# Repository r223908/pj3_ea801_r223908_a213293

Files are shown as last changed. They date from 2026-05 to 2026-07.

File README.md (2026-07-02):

### EA801 - PROJETO 3

### Câmbio CVT (v2) com BitDogLab V7

**Autores:** 
- Raul Galdino Tancredo (RA: 223908 / [@r223908](https://github.com/r223908))
- Arthur Lucas Da Silva Nogueira (RA: 213293 / [@arthurnog](https://github.com/arthurnog)))

**Professor:** Eric Rohmer

* **Proposta de projeto**: [Proposta em G-Docs](https://docs.google.com/document/d/12xUf4pp4VCcdJPwbZHKw6q6G0AQpYL8BC8JdEnKDbEA/edit?usp=sharing) (acesso "Comentador" para UNICAMP)
* **Relatório de projeto**: [Relatório em G-Docs](https://docs.google.com/document/d/11B9UFEimS15q4Ivua8mCu4cjH7NtBMuLyvma5xU35qU/edit?usp=sharing) (acesso "Comentador" para UNICAMP)
* **Demonstração do projeto no YouTube**: [Vídeo](https://youtube.com/shorts/MMiuudLj5G8)

---
## ⚙️ DESCRIÇÃO DO SISTEMA (v2)
O sistema desenvolvido consiste na implementação de uma bancada de testes para um **Câmbio de Transmissão Continuamente Variável (CVT)** simulado, controlado remotamente via interface sem fio. O projeto utiliza a plataforma BitDogLab V7 como unidade central de processamento, integrando comunicação serial, controle de potência e telemetria. O controle é dividido em dois eixos de atuação:
1. Eixo motor: Um motor de corrente contínua (DC), simulando a rotação do motor primário, controlado via PWM mas com a rotação travada em 100%.
2. Atuador do câmbio: Um segundo motor acoplado a um sistema de fuso (atuador linear), responsável por alterar a posição física da correia do câmbio CVT.

A interface homem-máquina (IHM) é realizada de forma remota através de um módulo Bluetooth (conectado à interface UART da placa) com a integração de um aplicativo no celular. O display OLED da placa é utilizado para exibir a telemetria em tempo real.

A realimentação da posição do atuador do CVT é realizada por meio de um sensor de distância óptico Time of Flight (ToF) VL6180X. Cabe ressaltar que o atual protótipo apresenta diversas otimizações mecânicas e elétricas em relação ao projeto original desenvolvido na etapa anterior da disciplina (PJ2).

<figure align="center">
    <figcaption><i>Diagrama de blocos do projeto.</i></figcaption>
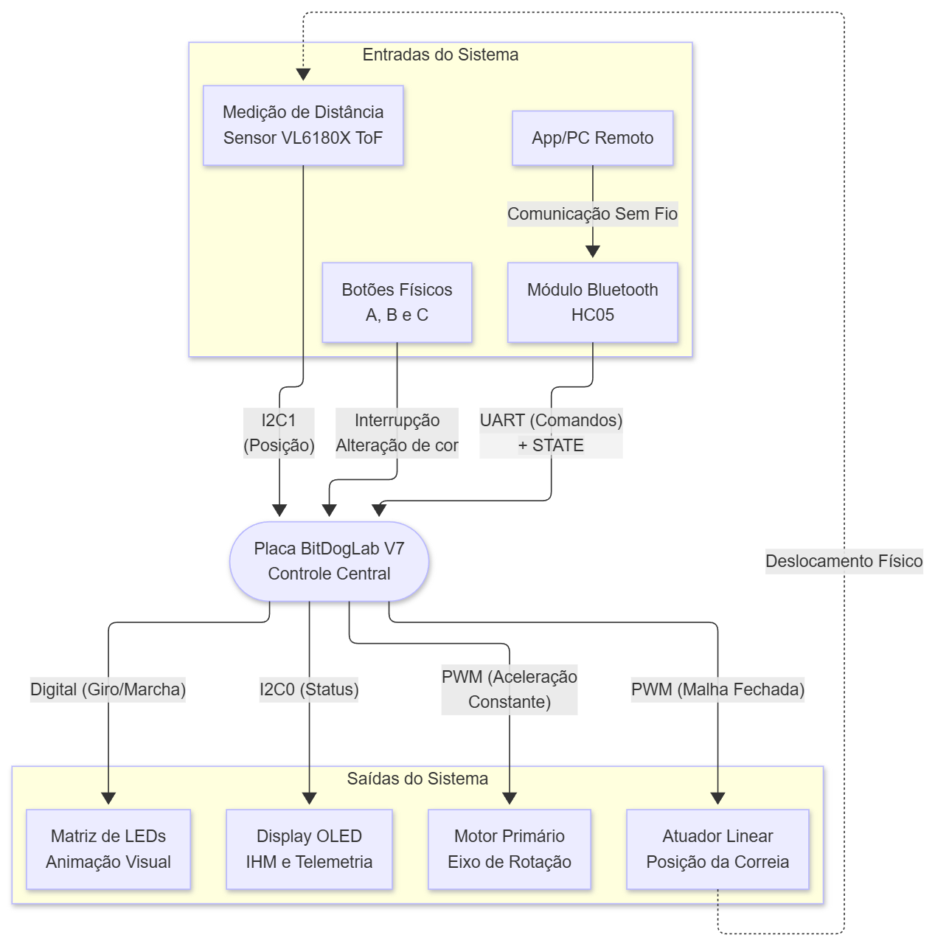
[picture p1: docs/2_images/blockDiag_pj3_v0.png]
    
    </br>
</figure>

<figure align="center">
    <figcaption>
        <i>Projeto em CAD 3D (PJ3).
        <br>PDF 3D (abrir com Foxit ou Adobe): <a href="https://github.com/r223908/pj3_ea801_r223908_a213293/blob/main/docs/6_CAD-files/ea801_pj3_cvt_pdf3D.PDF">/docs/6_CAD-files/ea801_pj3_cvt_pdf3D</a></i></i>
    </figcaption>
    <table align="center">
    <tr>
    <td align="center">
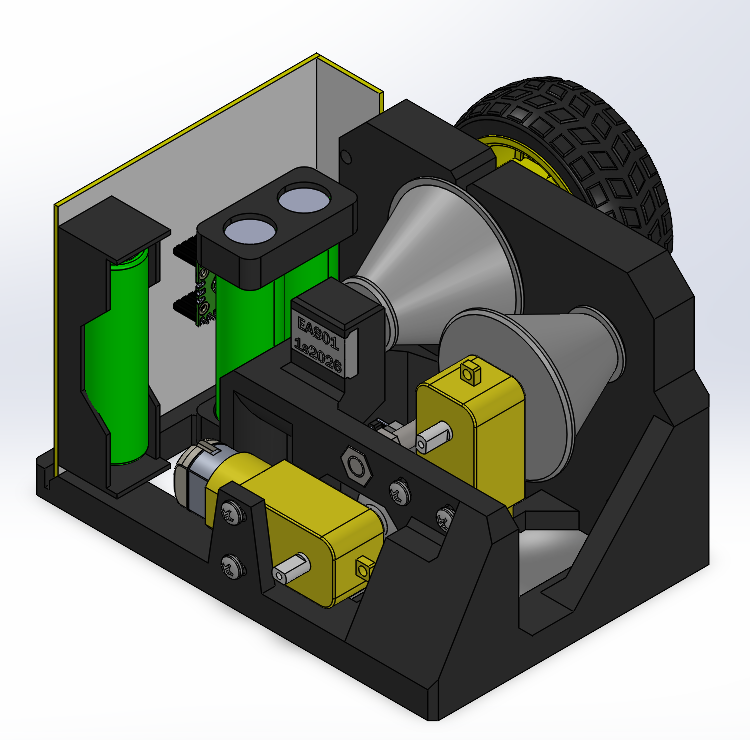
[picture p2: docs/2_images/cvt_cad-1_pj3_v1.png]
        <br>
    </td>
    <td align="center">
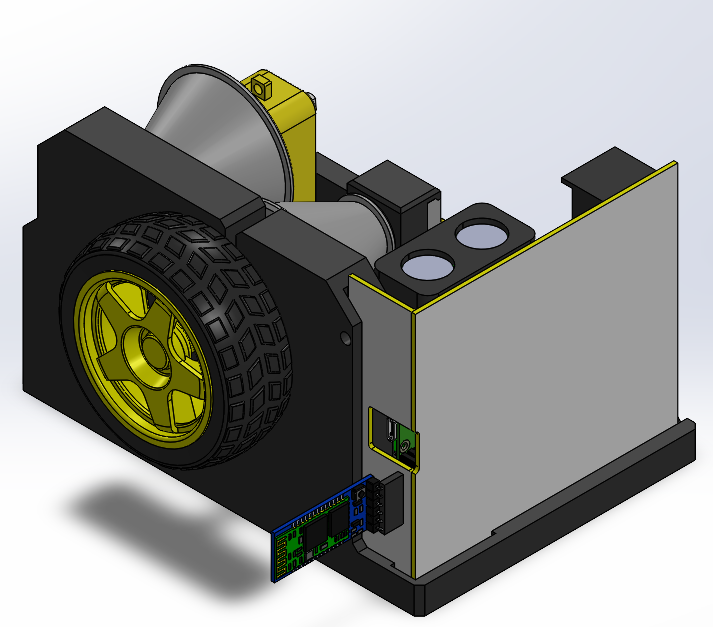
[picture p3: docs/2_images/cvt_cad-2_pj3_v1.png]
        <br>
    </td>
    </tr>
</table>
</figure>

<figure align="center">
    <figcaption>
        <i>Equipamento montado #1 (PJ3).</i>
    </figcaption>
    <table align="center">
    <tr>
    <td align="center">
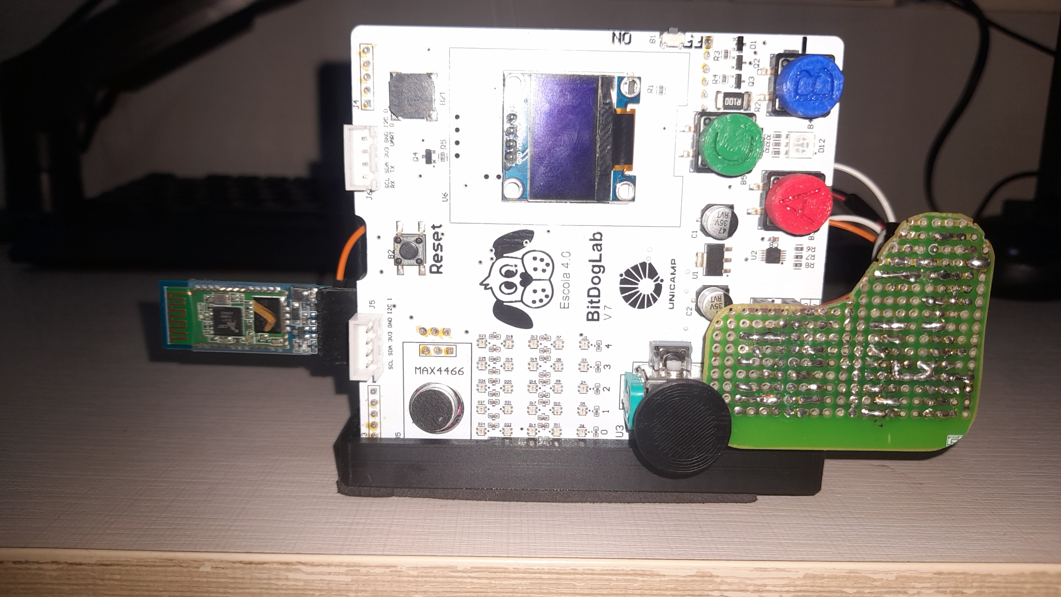
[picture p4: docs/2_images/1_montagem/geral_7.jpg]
        <br>
    </td>
    <td align="center">
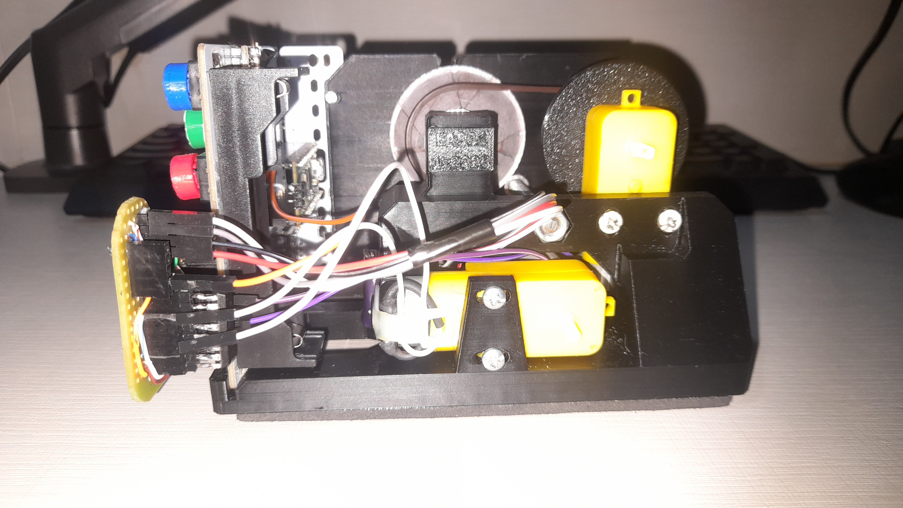
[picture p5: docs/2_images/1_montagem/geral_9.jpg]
        <br>
    </td>
    </tr>
</table>
</figure>

<figure align="center">
    <figcaption>
        <i>Equipamento montado #2 (PJ3).</i>
    </figcaption>
    <table align="center">
    <tr>
    <td align="center">
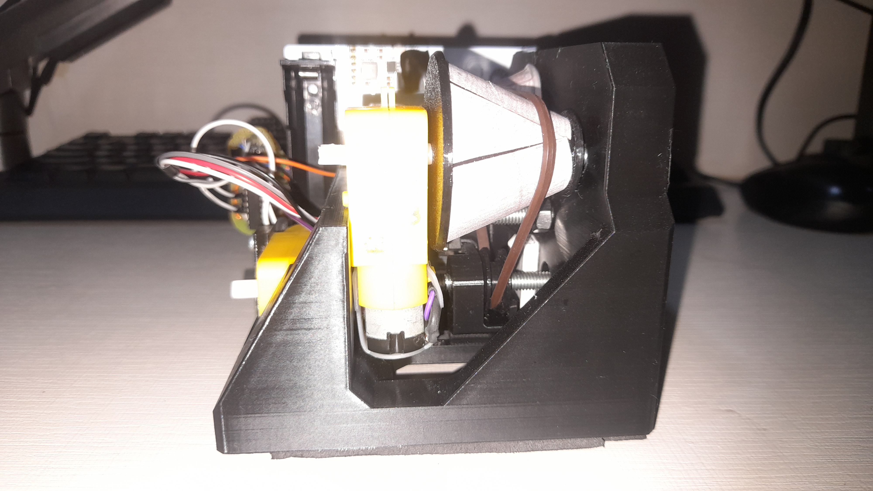
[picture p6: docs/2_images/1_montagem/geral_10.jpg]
        <br>
    </td>
    <td align="center">
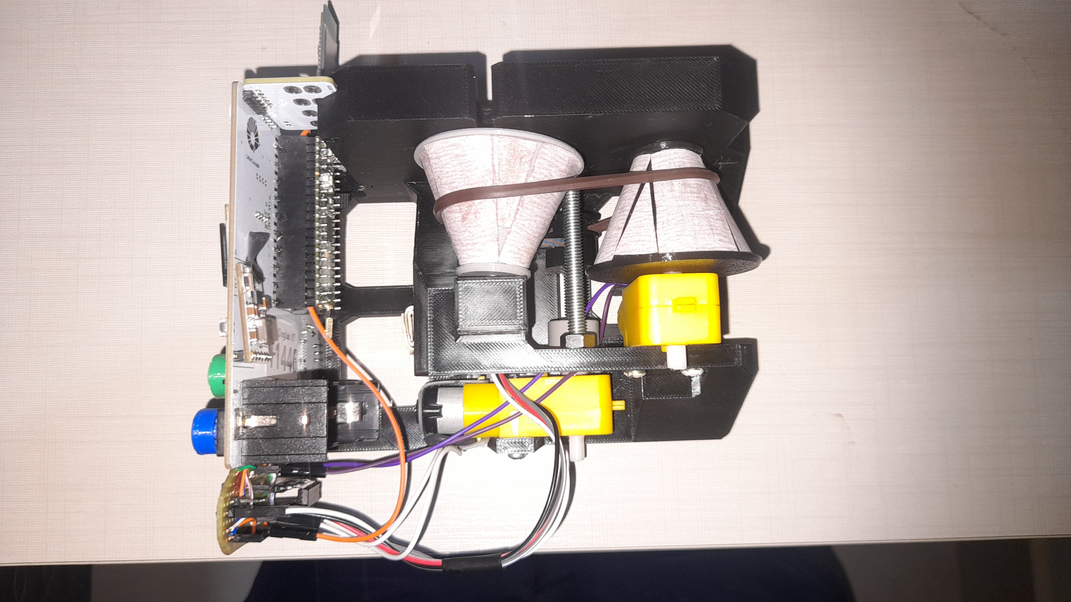
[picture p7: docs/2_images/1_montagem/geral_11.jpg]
        <br>
    </td>
    </tr>
</table>
</figure>

<figure align="center">
    <figcaption><i>Equipamento montado #3 (PJ3).</i></figcaption>
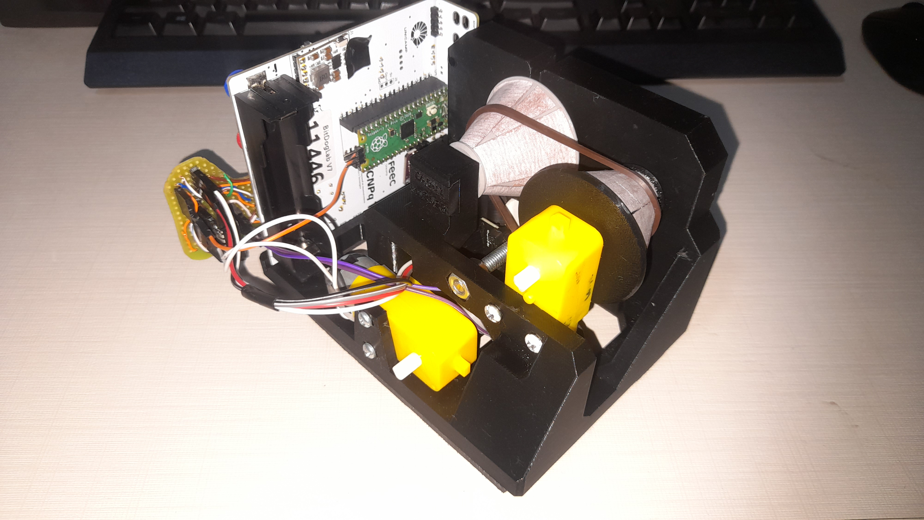
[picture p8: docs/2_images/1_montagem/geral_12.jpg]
    
    </br>
</figure>

---
## ❗REQUISITOS
- 1x BitDogLab V7.
- 2x motores DC com caixa de redução
- 2x capacitores cerâmicos 100 nF (cód.: 104)
- 1x Ponte H L293D (CI) para ambos os motores.
- 1x Sensor ToF VL6180X
- Placa de fenolite para a shield da BitDogLab
- Jumpers M-M e M-F.
- 3x pilhas 18650: 2x para os motores e 1x para a placa
- *Case* com cabos para 2 pilhas 18650 em paralelo.
- Cabo micro USB (usar apenas para passar a programação, com as pilhas desconectadas).
- Módulo Bluetooth HC-05.
- Anel o-ring ou elástico para o câmbio.
- Elementos de fixação
    - 1x Parafuso ISO 4017 M6x15 (Contra-eixo do cone principal)
    - 1x Parafuso ISO 4017 M6x60 (fuso do CVT)
    - 2x Porca ISO 4032 M6 (Espaçador no fuso do CVT e guia da polia)
    - 1x Arruela ISO 7093 Ø6 (Espaçador no fuso do CVT)
    - 4x Parafuso auto atarrachante 9/64"x1" (ou 1/8"x1" - Ø x Comprimento)
- Peças impressas em 3D
- Ambiente de desenvolvimento configurado para MicroPython.

---
## 🔧CONFIGURAÇÕES
- BitDogLab V7: Transferir os arquivos **main.py**, **setup.py**, **vl6180x.py** e **ssd1306.py** para a placa via USB.
- Ligação das pontes H e motores conforme **/docs/images/schematic_pj3.png**
- Módulo Bluetooth HC05 configurado com AT Mode usando **hc05_atMode_config.py**
- Sensor VL6180X calibrado conforme **/libs/tools/vl6180x_calibrate**

---
## 📚 REFERÊNCIAS
1. Repositório BitDogLab V7: [Repositório no GitHub](https://gitlab.unicamp.br/fabiano/bitdoglab-v7)
2. Banco de Informação de Hardware: [BitDogLabV7_BIH](https://docs.google.com/document/d/13-68OqiU7ISE8U2KPRUXT2ISeBl3WPhXjGDFH52eWlU/edit?tab=t.0)
3. LEGO Continuous Variable Transmission (CVT) V3 [Link YouTube](https://www.youtube.com/watch?v=sa60egMprYc)
4. LEGO Simple CVT (Continuously Variable Transmission) [Link YouTube](https://www.youtube.com/watch?v=1y5fQr0dDVg)
5. Time-of-Flight (ToF) proximity sensor and ambient light sensing (ALS) module [VL6180X](https://www.st.com/en/imaging-and-photonics-solutions/vl6180x.html)
6. Using one or more VL6180X 20cm Time-of-Flight proximity sensor with Arduino [Link YouTube](https://www.youtube.com/watch?v=_H9D0czQpSI)

---
## 📄LICENÇA
* Ver o arquivo `LICENSE`.

---
## 📂 ESTRUTURA DO PROJETO
``` text
├── .vscode/                        → Configurações para o ambiente de trabalho no VSCode
├── docs/                           → Documentação do projeto
│   ├── 1_folhas-de-dados/          → Folhas de dados dos equipamentos utilizados
│   ├── 2_images/                   → Imagens para relatórios e referências
│   ├── 3_mermaid-files/            → arquivos para gerar os diagramas de bloco e gantt
│   ├── 4_kicad-pj3/                → Projeto KiCad para a plaquinha shield
│   ├── 5_video/                    → Vídeo do equipamento em operação
│   ├── 6_CAD-files/                → Arquivos .stl e PDF_3D da montagem
│   └── (...)                       → Proposta e relatório
├── libs/
│   ├── tools/                      → Códigos para configuração dos equipamentos                           
│   └── (...)                       → Bibliotecas
├── src/                            
│   └── main.py                     → Código-fonte
├── .micropico                      → Arquivo necessário para a extensão Pi PICO no VSCODE
├── LICENSE                         → Licença de uso do código
└── README.md                       → Resumo e estrutura do projeto
```

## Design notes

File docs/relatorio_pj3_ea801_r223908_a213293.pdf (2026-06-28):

## UNICAMP - Universidade Estadual de Campinas

### FEEC - Faculdade de Engenharia Elétrica e de Computação

Câmbio CVT (v2) com BitDogLab V7 RELATÓRIO DE PROJETO

Link deste documento (acesso Comentador para UNICAMP): Link (https://docs.google.com/document/d/11B9UFEimS15q4Ivua8mCu4cjH7NtBMuLyvma5xU35qU/edit?usp=sharing) Repositório no GitHub (https://github.com/r223908/pj3_ea801_r223908_a213293)
Vídeo de demonstração (https://www.youtube.com/shorts/MMiuudLj5G8)
Arthur Lucas Da Silva Nogueira | RA: 213293
Raul Galdino Tancredo | RA: 223908

Prof. Eric Rohmer

Campinas
2026

### 1. Descrição do Sistema

O sistema desenvolvido consiste na implementação de um Câmbio de Transmissão Continuamente Variável (CVT) simulado e controlado remotamente via interface sem fio. O projeto utiliza a plataforma BitDogLab V7 como unidade central de processamento, integrando comunicação serial, controle de potência e telemetria. Utilizando uma ponte H L293D, o controle dos motores é dividido em dois eixos de atuação:
1. Eixo motor: motor de corrente contínua (DC) responsável pela força motriz principal, conectado ao cone principal.
2. Atuador do câmbio: motor de corrente contínua acoplado a um sistema de fuso (atuador linear), responsável por alterar a posição física da correia do câmbio CVT. No sistema de fuso, há a polia (que tem o anel o-ring/elástico girando livremente) e a guia, que faz com que o movimento de rotação do fuso se transforme em movimento linear.

A interface homem-máquina (IHM) é realizada de forma remota através de um módulo Bluetooth (conectado à interface UART da placa) com a integração de um aplicativo no celular (“Arduino Bluetooth Control” na Play Store do Google). O display OLED da placa é utilizado para exibir a telemetria em tempo real.

Para termos um controle de posicionamento do câmbio, foi incluído o sensor Time of Flight (ToF) VL6180X da STM. Com este sensor acoplado ao câmbio linear, temos um feedback de posicionamento para controlar a velocidade de saída do câmbio.

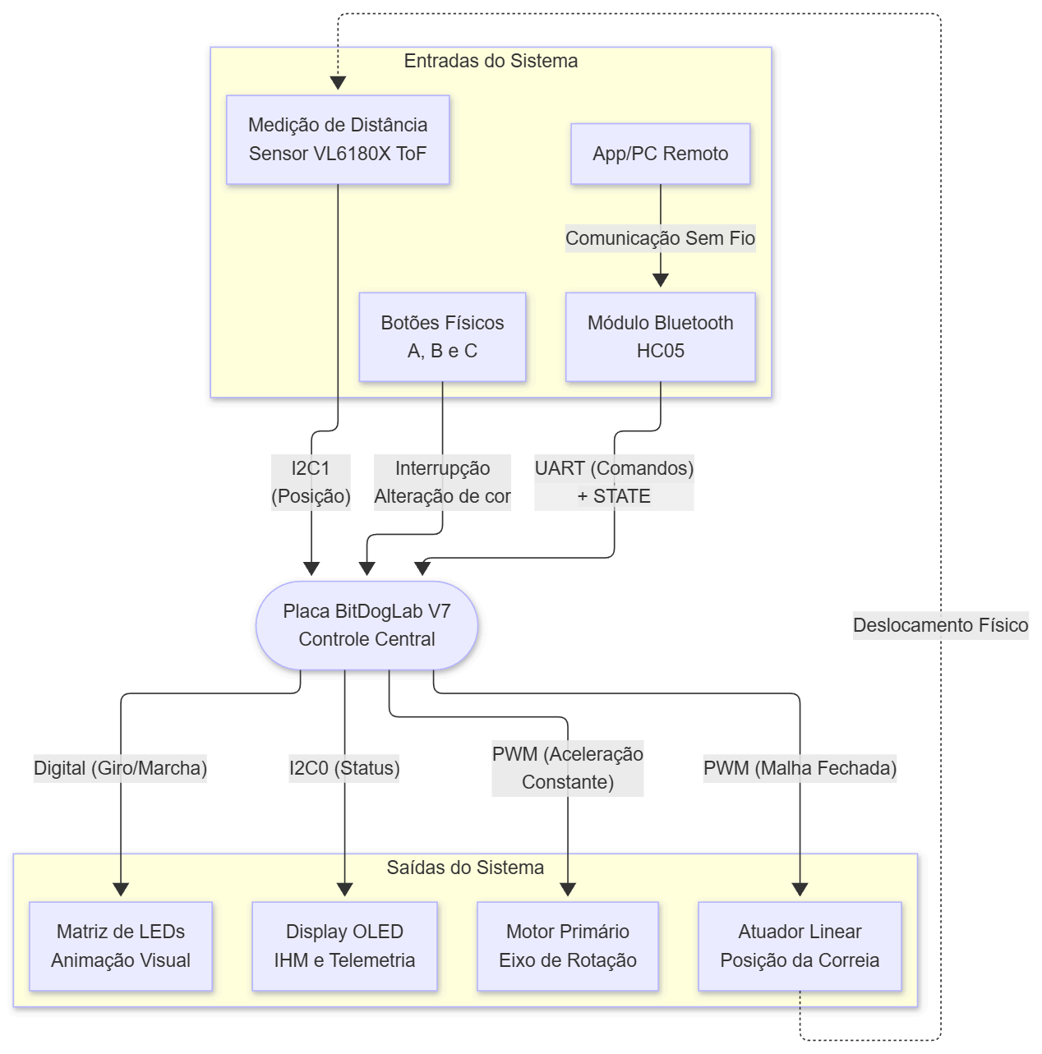
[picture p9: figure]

Figura 1 - Arquitetura do sistema.

### 2. Código fonte

- Códigos de configuração e teste:
- Configuração módulo Bluetooth: libs/tools/hc05_atMode_config.py (https://github.com/r223908/pj3_ea801_r223908_a213293/blob/main/libs/tools/hc05_atMode_config.py)
- Mapeamento de comandos Bluetooth: libs/tools/hc05_bluetooth_mapping.py (https://github.com/r223908/pj3_ea801_r223908_a213293/blob/main/libs/tools/hc05_bluetooth_mapping.py)
- Calibração do VL6180x: libs/tools/vl6180x_calibrate.py (https://github.com/r223908/pj3_ea801_r223908_a213293/blob/main/libs/tools/vl6180x_calibrate.py)
- Teste do VL6180x: libs/tools/vl6180x_test.py (https://github.com/r223908/pj3_ea801_r223908_a213293/blob/main/libs/tools/vl6180x_test.py)

Python

- Biblioteca do sensor VL6180X: libs/vl6180x.py (https://github.com/r223908/pj3_ea801_r223908_a213293/blob/main/libs/vl6180x.py)

"""
GitHub: https://github.com/Ledbelly2142/VL6180X/blob/master/vl6180x.py Author: Ledbelly2142 (https://github.com/Ledbelly2142)
"""

import ustruct
import struct
import time
from machine import I2C, Pin

i2c_tof = I2C(0, sda=Pin(8), scl=Pin(9)) offsetVal = 35

class Sensor:
def __init__(self, i2c, address=0x29): self.i2c_tof = i2c
self._address = address
self.default_settings()
self.init()

def myWrite16(self, register, regValue):
""" write a byte to specified 16 bit register """ return self.i2c_tof.writeto_mem(self._address, register, bytearray([regValue]), addrsize=16), 'big'

def myRead16(self, register):
"""read 1 bit from 16 byte register"""
value = int.from_bytes(
self.i2c_tof.readfrom_mem(self._address, register, 1, addrsize=16), 'big'
)
return value & 0xFFFF

def init(self):
if self.myRead16(0x0016) != 1:
raise RuntimeError("Failure reset")

# Recommended setup from the datasheet self.myWrite16(0x0207, 0x01) self.myWrite16(0x0208, 0x01) self.myWrite16(0x0096, 0x00) self.myWrite16(0x0097, 0xfd) self.myWrite16(0x00e3, 0x00) self.myWrite16(0x00e4, 0x04) self.myWrite16(0x00e5, 0x02) self.myWrite16(0x00e6, 0x01) self.myWrite16(0x00e7, 0x03) self.myWrite16(0x00f5, 0x02) self.myWrite16(0x00d9, 0x05) self.myWrite16(0x00db, 0xce)

self.myWrite16(0x00dc, 0x03) self.myWrite16(0x00dd, 0xf8) self.myWrite16(0x009f, 0x00) self.myWrite16(0x00a3, 0x3c) self.myWrite16(0x00b7, 0x00) self.myWrite16(0x00bb, 0x3c) self.myWrite16(0x00b2, 0x09) self.myWrite16(0x00ca, 0x09) self.myWrite16(0x0198, 0x01) self.myWrite16(0x01b0, 0x17) self.myWrite16(0x01ad, 0x00) self.myWrite16(0x00ff, 0x05) self.myWrite16(0x0100, 0x05) self.myWrite16(0x0199, 0x05) self.myWrite16(0x01a6, 0x1b) self.myWrite16(0x01ac, 0x3e) self.myWrite16(0x01a7, 0x1f) self.myWrite16(0x0030, 0x00)

def default_settings(self): self.myWrite16(0x0011, 0x10) self.myWrite16(0x010A, 0x30) self.myWrite16(0x003f, 0x46) self.myWrite16(0x0031, 0xFF) self.myWrite16(0x0040, 0x63) self.myWrite16(0x002E, 0x01) self.myWrite16(0x0024, 100) self.myWrite16(0x001B, 0x09) self.myWrite16(0x003E, 0x0A) self.myWrite16(0x0014, 0x24) self.myWrite16(0x002D, 0x10) self.myWrite16(0x0022, 0x28) self.myWrite16(0x001C, 0x3F) self.myWrite16(0x0120, 0x01)

def identify(self):
return {
'model': self.myRead16(0x0000),
'revision': (self.myRead16(0x0001), self.myRead16(0x0002)), 'module_revision': (self.myRead16(0x0003), self.myRead16(0x0004)), 'date': self.myRead16(0x006),
'time': self.myRead16(0x008),
}

def address(self, address=None): if address is None:
return self._address
if not 8 <= address <= 127:
raise ValueError("Wrong address") self.myWrite16(0x0212, address) self._address = address

Python

def range(self):
"""Previne falhas elétricas do hardware (I2C OSError) e retorna None de forma segura"""
try:
self.myWrite16(0x0018, 0x01) # Sysrange start

# Timeout simples para evitar travamento em loops infinitos caso o I2C congele

timeout = 50
while (self.myRead16(0x004F) & 0x04) == 0:
time.sleep(0.005)
timeout -= 1
if timeout <= 0:
print("Aviso: Timeout de leitura do sensor ToF.") return None

status = self.myRead16(0x004D) >> 4 distancia_crua = self.myRead16(0x0062) self.myWrite16(0x0015, 0x07) # Clear Interrupt

if status != 0:
print(f"Erro interno do ToF! Código: {status}") return None

distancia_real = distancia_crua
if distancia_real < 0:
distancia_real = 0

return (0 if ((distancia_real - offsetVal) < 0) else (distancia_real -offsetVal))

except OSError:
# Captura o erro EIO [Errno 5] físico sem derrubar o programa principal

print("Alerta: Falha física instantânea de comunicação I2C com o ToF.")
return None
- Setup do projeto: libs/setup.py (https://github.com/r223908/pj3_ea801_r223908_a213293/blob/main/libs/setup.py)

"""
arquivo de importação de bibliotecas, configuração de interfaces e variáveis """

from machine import Pin, ADC, I2C, PWM
import neopixel, utime, machine, time
import ssd1306, vl6180x

# 1. Variáveis Globais e Cores

corVermelha = (20, 0, 0)
corAzul = (0, 0, 20)
corVerde = (0, 20, 0)
cor_travada = corVermelha # Motor começa vermelho ultimo_tempo_btn = 0
ultimo_tempo_pisca = utime.ticks_ms() indice_frame = 0

# 2. Variáveis de Controle do Motor Virtual

CENTRO_JOYSTICK = 32768
ZONA_MORTA = 4000
MAX_LEDS_POR_SEGUNDO = 100 # Ajuste a velocidade máxima aqui

# 3. Configuração dos Botões (A, B e C)

botao_a = Pin(5, Pin.IN, Pin.PULL_UP)
botao_b = Pin(6, Pin.IN, Pin.PULL_UP)
botao_c = Pin(10, Pin.IN, Pin.PULL_UP)

# 4. Configuração do Joystick

joystick_x = ADC(Pin(27))
joystick_y = ADC(Pin(26))
joystick_sw = Pin(22, Pin.IN, Pin.PULL_UP)

# 5. Configuração do Display OLED (SSD1306)

# Usando os pinos I2C0 da BitDogLab V7 (SDA=2, SCL=3) i2c = I2C(1, scl=Pin(3), sda=Pin(2), freq=400000) display = ssd1306.SSD1306_I2C(128, 64, i2c, addr=0x3C) display.fill(0)

display.show()
ATT_DISPLAY_MS = 100

# 6. Configuração da Matriz de LEDs NUM_LEDS = 25

np = neopixel.NeoPixel(Pin(7), NUM_LEDS)
LED_MEIO = 12
# Buffer circular da animação do motor

FRAMES_MOTOR = [[14, 13], [15, 16], [16, 24], [16, 23], [17, 22], [18, 21], [18, 20], [18, 19], [10, 11], [8, 9], [0, 8], [1, 8], [2, 7], [3, 6], [4, 6], [5, 6] ]

# 7. Configuração dos controles de Motor (Ponte H) e PWM da placa

# IMPORTANTE: GPIO 0 e 1 são do Bluetooth. Vamos usar os pinos livres do conector IDC.

# Motor Principal (Eixo) - Assumindo ligação no lado Esquerdo do L293D (Pinos 1, 2 e 7)

Mprincipal_DIR1 = Pin(16, Pin.OUT)
Mprincipal_DIR2 = Pin(17, Pin.OUT)
Mprincipal_PWM = PWM(Pin(18)) | # GP28 vai no pino 1 (EN1,2) do L293D
Mprincipal_PWM.freq(1000)
Mprincipal_PWM.duty_u16(0)
TEMPO_RAMPA_MS = 1000

Python

# Motor Câmbio (Atuador CVT) - EXATAMENTE COMO NO SEU ESQUEMÁTICO (Lado Direito)

Mcambio_DIR1 = Pin(19, Pin.OUT) | # GP18 (Fio Roxo) vai no IN3
Mcambio_DIR2 = Pin(20, Pin.OUT) | # GP20 (Fio Branco) vai no IN4
Mcambio_PWM = PWM(Pin(28)) | # GP19 (Fio Cinza) vai no EN3,4 (Enable/PWM)
Mcambio_PWM.freq(1000)
Mcambio_PWM.duty_u16(0)
TEMPO_PASSO_CVT_MS = 5000 # 2000 ms = 2 segundos

# 8. Configura o LED Azul da placa (GPIO 12) para feedback visual led_azul = machine.Pin(12, machine.Pin.OUT)

led_azul.value(0) # Inicia desligado

# 9. Inicializa a UART0 para o Bluetooth (Pinos do Conector J2)

bluetooth = machine.UART(0, baudrate=9600, tx=machine.Pin(0), rx=machine.Pin(1)) status_bt = machine.Pin(4, machine.Pin.IN) # Pino que vai ler o pino 'STATE' do módulo Bluetooth

# 10. Mapeamento das entradas bluetooth

outButtonDir = '0'
frontDir = 'F'
backDir = 'B'
rightDir = 'R'
leftDir = 'L'
triangleDir = 'T'
circleDir = 'C'
squareDir = 'S'
crossDir = 'X'
startDir = 'A'
pauseDir = 'P'

# 11. Inicializa o sensor

#i2c_tof = I2C(0, sda=Pin(8), scl=Pin(9)) #esta declaracao já está na biblioteca do sensor ToF

i2c_tof = vl6180x.i2c_tof
sensor_tof = vl6180x.Sensor(i2c_tof) # type: ignore
- Arquivo principal: link

from setup import *

# VARIÁVEIS PARA O CVT ASSÍNCRONO BASEADO EM DISTÂNCIA cvt_em_movimento = False

direcao_cvt = 0 | # 1 avança (diminui mm), -1 recua (aumenta mm)
alvo_tof_mm = 0.0 | # Distância que queremos atingir
janela_leituras = [] | # type: list[float]
TAMANHO_JANELA = 30 | # Média das últimas 30 leituras
PASSO_MM = 4.0 | # Quantos mm o câmbio anda por vez
MAX_DIST_MM = 24.0 | # Fundo do câmbio (0%)

MIN_DIST_MM = 1.0 # Batente do câmbio (100%)

# ==========================================

# FUNÇÕES DE HARDWARE (MOTORES, TELA E SENSOR)

# ==========================================

# MÉTODO DE LEITURA E SINCRONIZAÇÃO DO SENSOR TOF

def sincronizar_posicao_cvt():
global posicao_cvt
print("Sincronizando posição atual do sensor ToF...") leituras_locais = []

# Coleta 10 amostras rápidas para ignorar ruídos de leitura única for _ in range(10):

leitura = sensor_tof.range()
if leitura is not None and leitura > 0: leituras_locais.append(leitura)
utime.sleep(0.01)

if len(leituras_locais) > 0:
distancia_calculada = sum(leituras_locais) / len(leituras_locais) else:
# Se falhar totalmente por erro I2C, assume a última posição segura conhecida

distancia_calculada = MAX_DIST_MM

# Trava dentro dos limites físicos do projeto

distancia_calculada = max(MIN_DIST_MM, min(MAX_DIST_MM, distancia_calculada))

# 1. Atualiza a variável global de porcentagem

porcentagem_calculada = ((MAX_DIST_MM - distancia_calculada) / (MAX_DIST_MM -MIN_DIST_MM)) * 100
posicao_cvt = max(0, min(100, int(porcentagem_calculada)))

print(f"Posição Sincronizada: {distancia_calculada:.1f} mm ({posicao_cvt}%)") return distancia_calculada

# Lida com as informações do display OLED

def printOled(velocidade, direcao, posicao_cvt, bt_conectado):
texto_sentido = "Horario" if direcao == 1 else "Anti-Hor." texto_sentido = "Parado" if velocidade == 0 else texto_sentido texto_bt = "ON" if bt_conectado == 1 else "OFF" display.fill(0)
display.text("Cambio CVT", 20, 0)
display.text("-" * 16, 0, 10) display.text(f"Motor: {texto_sentido}", 0, 25) display.text(f"Pos. CVT: {posicao_cvt}%", 0, 40) display.text(f"Bluetooth: {texto_bt}", 0, 55) display.show()

# Controle do motor principal

def controlar_motor_principal(velocidade_percentual, direcao, fazer_rampa=False): if fazer_rampa and velocidade_percentual > 0:
passos = 10
tempo_por_passo = (TEMPO_RAMPA_MS / 2000) / passos passo_pwm = max(1, velocidade_percentual // passos) for v in range(velocidade_percentual, -1, -passo_pwm): Mprincipal_PWM.duty_u16(int((v / 100) * 65535)) utime.sleep(tempo_por_passo) Mprincipal_DIR1.value(0)
Mprincipal_DIR2.value(0)
Mprincipal_PWM.duty_u16(0) utime.sleep(0.05)
if direcao == 1:
Mprincipal_DIR1.value(1)
Mprincipal_DIR2.value(0)
else:
Mprincipal_DIR1.value(0)
Mprincipal_DIR2.value(1)
for v in range(0, velocidade_percentual + 1, passo_pwm): Mprincipal_PWM.duty_u16(int((v / 100) * 65535)) utime.sleep(tempo_por_passo) Mprincipal_PWM.duty_u16(int((velocidade_percentual / 100) * 65535)) else:
if velocidade_percentual > 0:
if direcao == 1:
Mprincipal_DIR1.value(1)
Mprincipal_DIR2.value(0)
else:
Mprincipal_DIR1.value(0)
Mprincipal_DIR2.value(1)
else:
Mprincipal_DIR1.value(0)
Mprincipal_DIR2.value(0)
Mprincipal_PWM.duty_u16(int((velocidade_percentual / 100) * 65535))

# Movimentação do câmbio, velocidade sempre em 100% def iniciar_movimento_cvt(direcao):

if direcao == 1:
Mcambio_DIR1.value(1)
Mcambio_DIR2.value(0)
elif direcao == -1:
Mcambio_DIR1.value(0)
Mcambio_DIR2.value(1)
else:
return
Mcambio_PWM.duty_u16(65535)

# VARIÁVEIS DE CONTROLE DOS BOTÕES FÍSICOS flag_homing = False

flag_cancelar = False

# ==========================================

# Função de Interrupção dos Botões

# ==========================================

def trata_interrupcao_botao(pino):
global cor_travada, ultimo_tempo_btn, flag_homing, flag_cancelar tempo_atual = utime.ticks_ms()

if utime.ticks_diff(tempo_atual, ultimo_tempo_btn) > 200:
if pino == botao_a:
cor_travada = corVermelha
flag_homing = True # Solicita o Homing (Voltar a 0%) elif pino == botao_b:
cor_travada = corAzul
elif pino == botao_c:
cor_travada = corVerde
flag_cancelar = True # Solicita a Parada Total (E-Stop)

ultimo_tempo_btn = tempo_atual

botao_a.irq(trigger=Pin.IRQ_FALLING, handler=trata_interrupcao_botao) botao_b.irq(trigger=Pin.IRQ_FALLING, handler=trata_interrupcao_botao) botao_c.irq(trigger=Pin.IRQ_FALLING, handler=trata_interrupcao_botao)

# ==========================================

# INICIALIZAÇÃO E LOOP PRINCIPAL

# ==========================================

ultimo_tempo_pisca = utime.ticks_ms() ultimo_tempo_oled = utime.ticks_ms()

velocidade_atual = 0
direcao_motor = 1

# --- CHAMADA DO MÉTODO ANTES DO WHILE (POSIÇÃO INICIAL) ---distancia_inicial = sincronizar_posicao_cvt()

cvt_em_movimento = False
ultimo_tempo_cvt = 0

for i in range(NUM_LEDS):
np[i] = (0, 0, 0)
np.write()

print("Aguardando comandos Bluetooth...")

while True:
tempo_atual = utime.ticks_ms()

# =================================================== # AÇÃO DE EMERGÊNCIA / CANCELAR (BOTÃO C)

# =================================================== if flag_cancelar:

flag_cancelar = False

velocidade_atual = 0
controlar_motor_principal(0, direcao_motor)

Mcambio_DIR1.value(0)
Mcambio_DIR2.value(0)
Mcambio_PWM.duty_u16(0)
cvt_em_movimento = False

print("BOTAO C: Parada de Emergencia Acionada!")

# =================================================== # AÇÃO DE HOMING / RETORNO À BASE (BOTÃO A)

# =================================================== if flag_homing:

flag_homing = False
if not cvt_em_movimento:
alvo_tof_mm = MAX_DIST_MM
direcao_cvt = -1

# --- CHAMADA DO MÉTODO DURANTE O FUNCIONAMENTO ---leitura_estavel = sincronizar_posicao_cvt()

# Inicializa a janela com o valor atualizado e limpo janela_leituras = [leitura_estavel] * TAMANHO_JANELA

iniciar_movimento_cvt(direcao_cvt)
cvt_em_movimento = True
print(f"BOTAO A: Homing iniciado a partir de {leitura_estavel:.1f} mm...")

# 1. ATUALIZAÇÃO DO DISPLAY OLED

if utime.ticks_diff(tempo_atual, ultimo_tempo_oled) >= ATT_DISPLAY_MS: estado_conexao = status_bt.value()
if estado_conexao == 0 and velocidade_atual > 0:
passos = 10
tempo_por_passo = (TEMPO_RAMPA_MS / 2000) / passos passo_pwm = max(1, velocidade_atual // passos)
for v in range(velocidade_atual, -1, -passo_pwm): Mprincipal_PWM.duty_u16(int((v / 100) * 65535)) utime.sleep(tempo_por_passo)
velocidade_atual = 0
controlar_motor_principal(0, direcao_motor) printOled(velocidade_atual, direcao_motor, posicao_cvt, estado_conexao) ultimo_tempo_oled = tempo_atual

# 2. LEITURA DE COMANDOS BLUETOOTH

if bluetooth.any():
try:
dados_brutos = bluetooth.read()
if dados_brutos is not None:
comando = dados_brutos.decode('utf-8').strip().upper()

if comando:
led_azul.value(1)

if comando == startDir:
velocidade_atual = 100
controlar_motor_principal(velocidade_atual, direcao_motor)

elif comando == frontDir:
deve_fazer_rampa = (direcao_motor == -1 and velocidade_atual > 0)
direcao_motor = 1
controlar_motor_principal(velocidade_atual, direcao_motor, deve_fazer_rampa)

elif comando == backDir:
deve_fazer_rampa = (direcao_motor == 1 and velocidade_atual > 0)
direcao_motor = -1
controlar_motor_principal(velocidade_atual, direcao_motor, deve_fazer_rampa)

elif comando == triangleDir: # Sobe marcha (Avança / Diminui mm)
if not cvt_em_movimento:
leitura_atual = sensor_tof.range() if leitura_atual is not None:
if leitura_atual > MIN_DIST_MM:
alvo_tof_mm = max(MIN_DIST_MM, leitura_atual -PASSO_MM)
direcao_cvt = 1
iniciar_movimento_cvt(direcao_cvt) cvt_em_movimento = True
janela_leituras = [leitura_atual] * TAMANHO_JANELA
elif comando == crossDir: | # Desce marcha (Recua /
Aumenta mm)
if not cvt_em_movimento:
leitura_atual = sensor_tof.range() if leitura_atual is not None:
if leitura_atual < MAX_DIST_MM:
alvo_tof_mm = min(MAX_DIST_MM, leitura_atual + PASSO_MM)
direcao_cvt = -1
iniciar_movimento_cvt(direcao_cvt) cvt_em_movimento = True
janela_leituras = [leitura_atual] * TAMANHO_JANELA

elif comando == pauseDir:
velocidade_atual = 0
controlar_motor_principal(0, direcao_motor)

Mcambio_DIR1.value(0)
Mcambio_DIR2.value(0)
Mcambio_PWM.duty_u16(0)
cvt_em_movimento = False

led_azul.value(0)
except UnicodeError:
pass

# 3. VERIFICADOR ASSÍNCRONO DO MOTOR CVT (MÉDIA MÓVEL COM TRAVA PARA 0MM) if cvt_em_movimento:

nova_leitura = sensor_tof.range()
chegou_no_alvo = False

# Se houver erro I2C (None) em movimento, assume o último dado estável para não travar o loop

if nova_leitura is None:
nova_leitura = janela_leituras[-1] if len(janela_leituras) > 0 else MAX_DIST_MM

# --- FILTRO INTELIGENTE E ANTITRAVAMENTO ---

if nova_leitura == 0:
if direcao_cvt == 1 and len(janela_leituras) > 0 and janela_leituras[-1] <= (MIN_DIST_MM + 3.0): chegou_no_alvo = True
nova_leitura = MIN_DIST_MM
print("Seguranca: Sensor detectou colisao/fim de curso em 0mm!") else:
nova_leitura = janela_leituras[-1] if len(janela_leituras) > 0 else MAX_DIST_MM
elif nova_leitura > 50:
nova_leitura = janela_leituras[-1] if len(janela_leituras) > 0 else MAX_DIST_MM

janela_leituras.pop(0)
janela_leituras.append(nova_leitura)

media_atual = sum(janela_leituras) / TAMANHO_JANELA

porcentagem = ((MAX_DIST_MM - media_atual) / (MAX_DIST_MM - MIN_DIST_MM)) * 100
posicao_cvt = max(0, min(100, int(porcentagem)))

# 1. Validação de Alvo

if direcao_cvt == 1 and media_atual <= alvo_tof_mm: chegou_no_alvo = True
elif direcao_cvt == -1 and media_atual >= (alvo_tof_mm - 0.5): chegou_no_alvo = True

# 2. Trava de Segurança dos Batentes Físicos (Baseado na Média) if media_atual <= MIN_DIST_MM and direcao_cvt == 1: chegou_no_alvo = True

print("Seguranca: Batente Minimo atingido pela media!") elif media_atual >= MAX_DIST_MM and direcao_cvt == -1: chegou_no_alvo = True
print("Seguranca: Batente Maximo atingido pela media!")

# 3. Execução Correta da Parada

if chegou_no_alvo:
Mcambio_DIR1.value(0)
Mcambio_DIR2.value(0)
Mcambio_PWM.duty_u16(0)
cvt_em_movimento = False

if direcao_cvt == -1 and media_atual >= (MAX_DIST_MM - 1.0): posicao_cvt = 0
print(f"Cambio Parado. Posicao Final: {posicao_cvt}% ({media_atual:.1f} mm)")

utime.sleep(0.01)

### 3. Desenvolvimento de Projeto

a) CAD 3D - Projeto mecânico
Aplicando algumas melhorias em relação ao projeto 2, foi feita uma nova estrutura com o auxílio de um software CAD. Paredes mais espessas, mudança nas posições dos motores, revisão da posição do eixo do câmbio, etc.

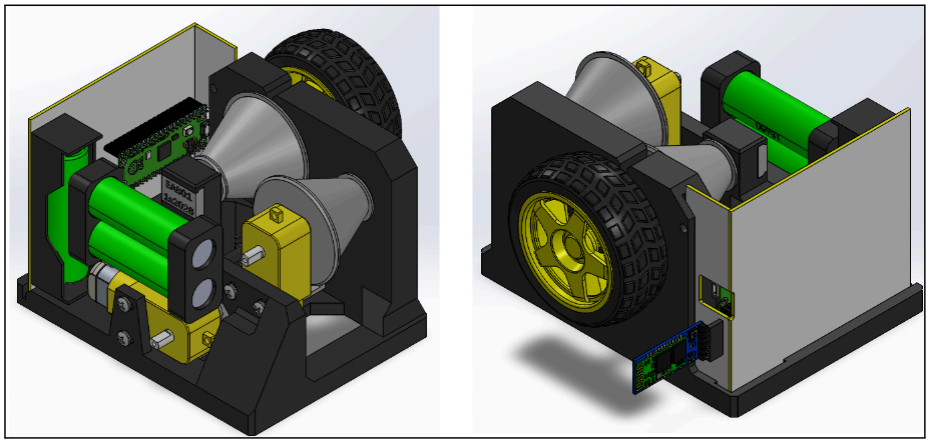
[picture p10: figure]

Figura 2 - Projeto CAD (versão 2).

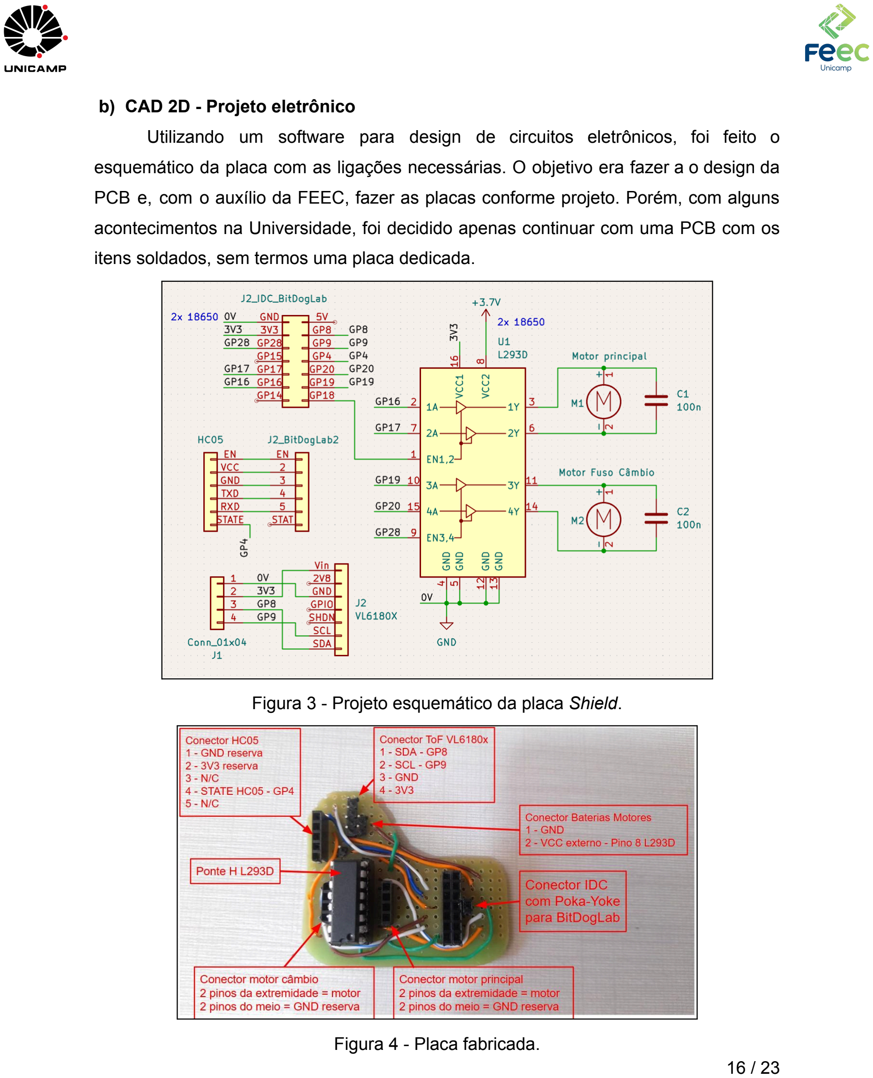
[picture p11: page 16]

b) CAD 2D - Projeto eletrônico
Utilizando um software para design de circuitos eletrônicos, foi feito o esquemático da placa com as ligações necessárias. O objetivo era fazer a o design da PCB e, com o auxílio da FEEC, fazer as placas conforme projeto. Porém, com alguns acontecimentos na Universidade, foi decidido apenas continuar com uma PCB com os itens soldados, sem termos uma placa dedicada.

Figura 3 - Projeto esquemático da placa Shield.

Figura 4 - Placa fabricada.

### 4. Montagem e desvios de projeto

Com os arquivos .stl, as peças foram impressas e o equipamento foi montado. Como desvios de projeto, foi adicionado um parafuso ao eixo do motor principal para diminuir atrito no giro, as superfícies dos cones tiveram pedaços de lixas colados para aumentar o atrito entre o elástico e o cone e a superfície refletora do ToF foi feita com um pedaço de papel cartão branco pois o plástico utilizado na estrutura é da cor preta, o que diminui a eficácia das leituras do ToF.

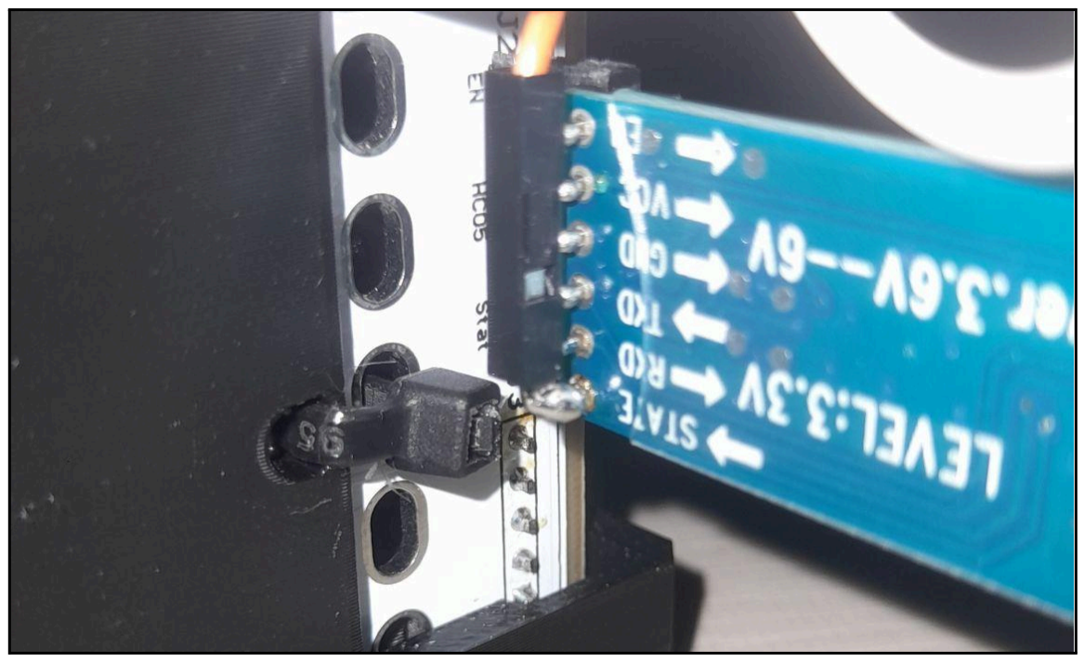
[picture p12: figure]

Figura 5 - Jumper soldado no pino de state para ser conectado na shield (STATE→GP4).

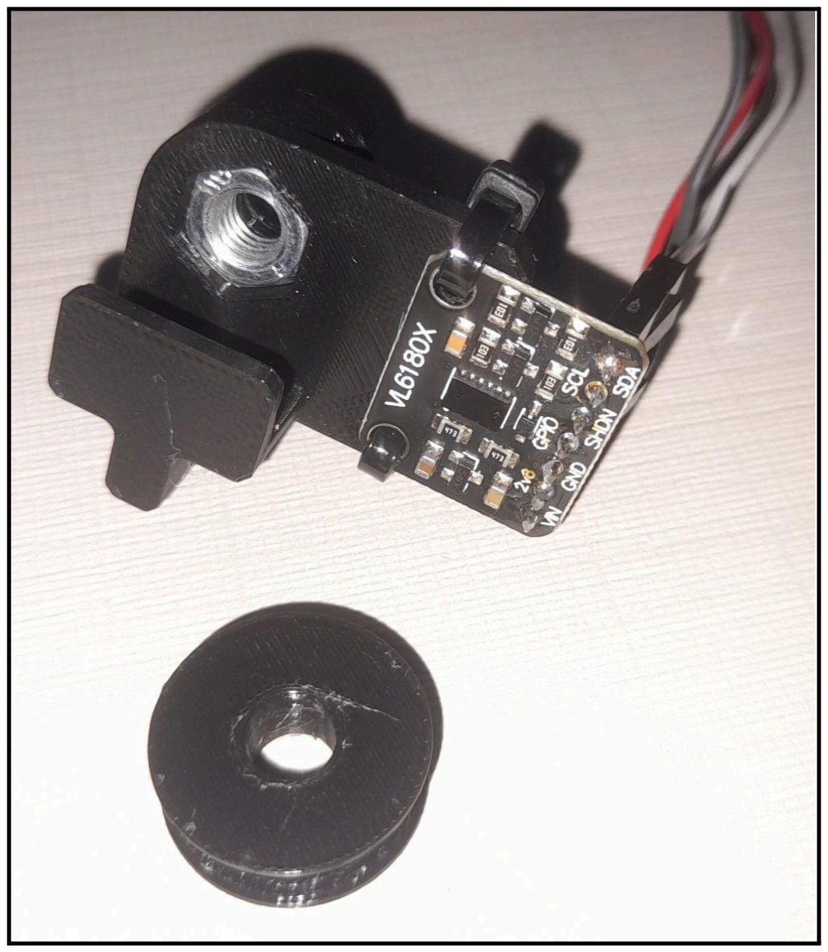
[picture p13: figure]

Figura 6 - Sistema de guia linear do eixo, com sensor ToF.

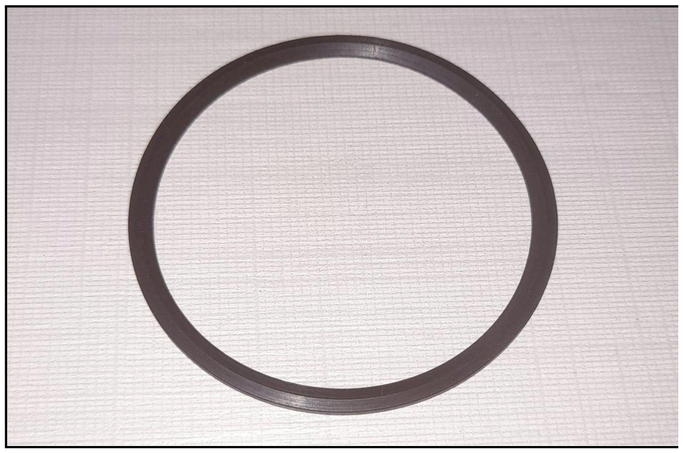
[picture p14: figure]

Figura 7 - Anel de vedação utilizado como correia.

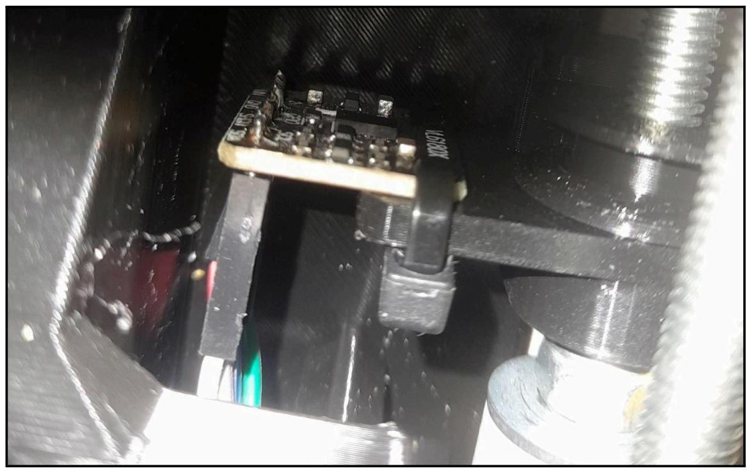
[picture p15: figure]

Figura 8 - Guia linear montada no eixo do câmbio.

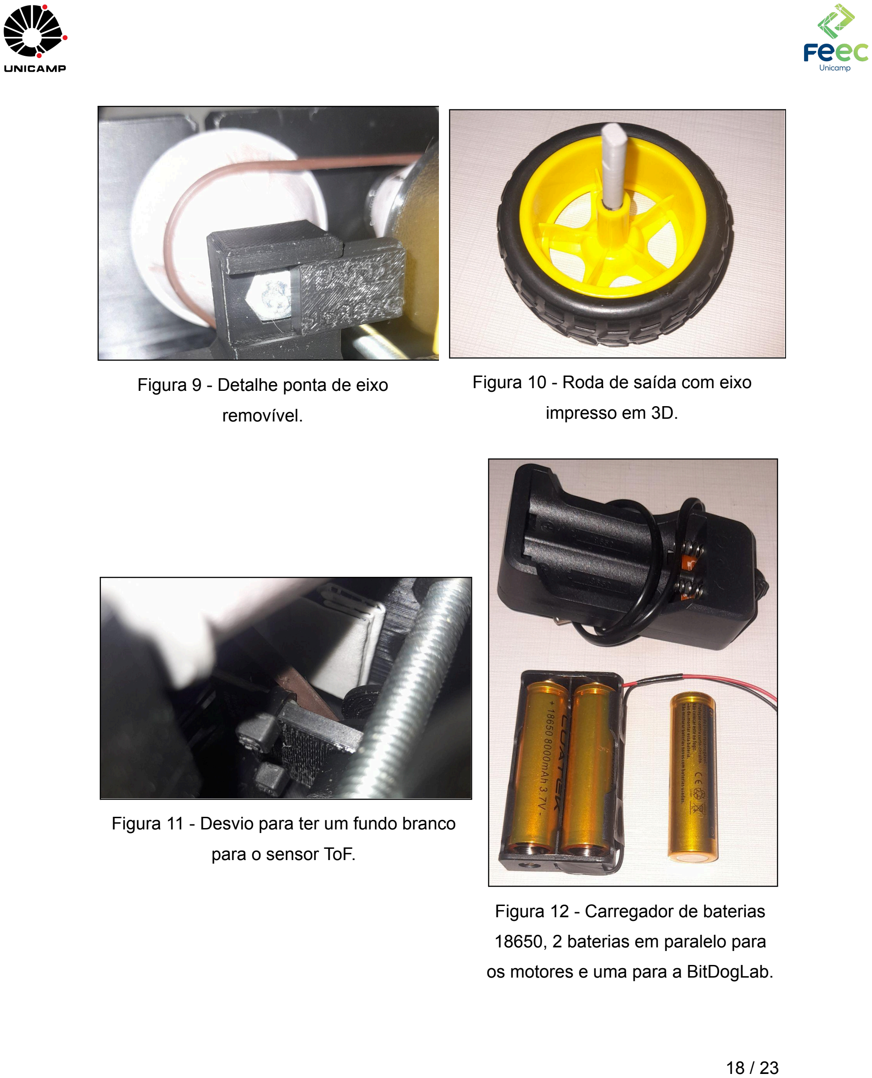
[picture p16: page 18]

Figura 9 - Detalhe ponta de eixo removível.

Figura 10 - Roda de saída com eixo impresso em 3D.

Figura 11 - Desvio para ter um fundo branco para o sensor ToF.

Figura 12 - Carregador de baterias 18650, 2 baterias em paralelo para os motores e uma para a BitDogLab.

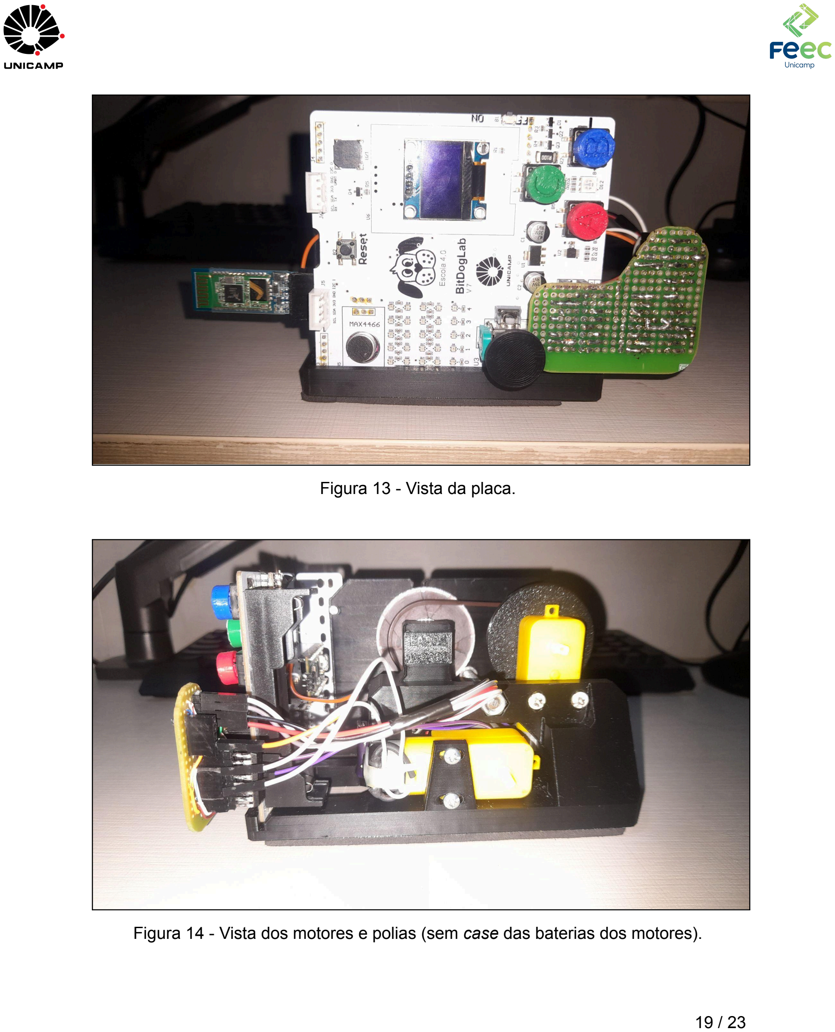
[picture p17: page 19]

Figura 13 - Vista da placa.

Figura 14 - Vista dos motores e polias (sem case das baterias dos motores).

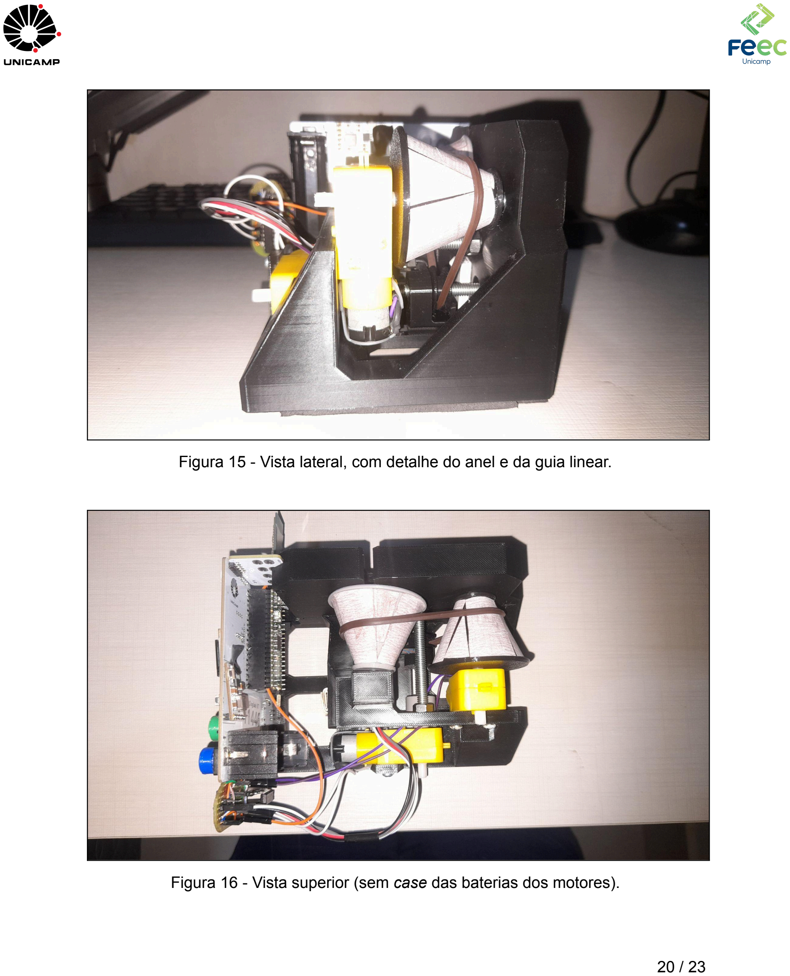
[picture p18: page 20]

Figura 15 - Vista lateral, com detalhe do anel e da guia linear.

Figura 16 - Vista superior (sem case das baterias dos motores).

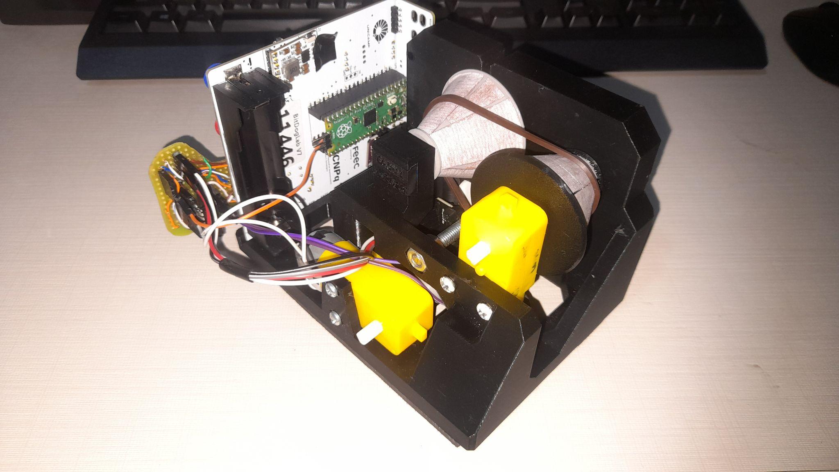
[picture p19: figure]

Figura 17 - Vista isométrica (sem case das baterias dos motores).

### 5. Testes realizados

A partir dos arquivos do projeto 2, era necessário implementar o controle via sensor ToF. Para isso, foi encontrada uma biblioteca no GitHub do sensor VL6180x para a placa ESP32.
A partir do código fonte desta biblioteca, e com o uso da ferramenta IA Gemini, foi criado o arquivo vl6180x.py. (https://github.com/r223908/pj3_ea801_r223908_a213293/blob/main/libs/vl6180x.py) A fim de afinar os parâmetros da biblioteca, foram criados outros dois códigos:
- Arquivo de calibração (vl6180x_calibrate.py): (https://github.com/r223908/pj3_ea801_r223908_a213293/blob/main/libs/tools/vl6180x_calibrate.py) Disponibiliza um valor de offset para ser inputado no arquivo vl6180x.py (https://github.com/r223908/pj3_ea801_r223908_a213293/blob/main/libs/vl6180x.py) (biblioteca).
- Arquivo de teste (vl6180x_test.py): (https://github.com/r223908/pj3_ea801_r223908_a213293/blob/main/libs/tools/vl6180x_test.py) Exibe no Terminal, periódicamente, o valor da leitura do sensor ToF.
Com estes arquivos, foi possível verificar que o sensor possui um range de detecção mínimo de 40 mm padrão (conforme datasheet) e que isso pode ser ajustado alterando o valor armazenado em um endereço de memória, tarefa esta realizada ao importar o arquivo vl6180x.py (https://github.com/r223908/pj3_ea801_r223908_a213293/blob/main/libs/vl6180x.py) em setup.py (https://github.com/r223908/pj3_ea801_r223908_a213293/blob/main/libs/setup.py) (endereço de memória 0x024, SYSRANGE__PART_TO_PART_RANGE_OFFSET). Além disso, notou-se que a leitura só era eficaz quando a superfície utilizada para reflexão do sinal infravermelho possui cores claras.
Com o sensor ToF montado na guia linear do câmbio, pedaços de lixas colados nos cones e sistema montado, os testes detectaram grande atrito que não permitia que o sistema girasse de maneira alguma. Por conta da situação de eixo travado, o consumo de corrente na ponte H L293D começou a afetar o funcionamento do motor do eixo.
Com isso, mais funções foram adicionadas ao sistema:
- Botão A: função de Homing, que busca trazer o câmbio para a posição inicial. Por se tratar de um sistema sem embreagem, é recomendado deixar o motor principal girando para não forçar os cones e o motor principal.
- Botão C: botão de emergência, que ao ser pressionado irá interromper qualquer tipo de acionamento dos motores ou funções específicas (e.g. Homing)

### 6. Conclusão

A realização deste projeto consolidou, de forma prática, os conceitos de integração entre hardware e software no desenvolvimento de sistemas mecatrônicos. O desenvolvimento da segunda versão do Câmbio de Transmissão Continuamente Variável (CVT) com a plataforma BitDogLab V7 permitiu uma exploração profunda dos desafios reais da engenharia, unindo projeto mecânico em CAD, eletrônica e programação de controle em malha fechada.
Durante a execução, diversos obstáculos físicos precisaram ser contornados para viabilizar o funcionamento mecânico. O alto atrito no giro e as limitações de aderência exigiram adaptações práticas, como a colagem de pedaços de lixa na superfície dos cones para garantir a tração da correia (anel de vedação). Além disso, a eficiência reflexiva do sensor Time of Flight (ToF) VL6180X foi inicialmente prejudicada pela cor preta do plástico impresso em 3D, problema este solucionado com um pedaço de papel branco, assegurando o retorno adequado do sinal infravermelho e leituras confiáveis de posicionamento.
Do lado da eletrônica e do software, o projeto exigiu grande robustez para lidar com a alta demanda de corrente e os ruídos provenientes do acionamento dos motores via ponte H L293D, que chegaram a afetar a comunicação no barramento I2C. A implementação de um filtro de média móvel para os dados de distância, aliada aos tratamentos de exceção no driver do sensor para suportar falhas físicas instantâneas sem travar o código principal, garantiu que o firmware em MicroPython operasse de maneira assíncrona, fluida e ininterrupta.
Por fim, o sistema alcançou plenamente os objetivos propostos. A integração do aplicativo de celular operando via módulo Bluetooth HC-05 funcionou em perfeita sincronia com a IHM do display OLED, que exibiu a telemetria em tempo real das ações de controle. O trabalho evidenciou não apenas a viabilidade da BitDogLab V7 como unidade central de processamento, mas, principalmente, a importância da iteração contínua para refinar um projeto e superar as severas limitações físicas impostas pelo mundo real.

### 7. Referências

- FRUETT, F. BitDogLab V7: repositório oficial. Campinas: Unicamp, 2024. Disponível em: https://gitlab.unicamp.br/fabiano/bitdoglab-v7.
- FRUETT, F. Banco de informações da BitDogLab V7. [S. l.], 2024. Disponível em: https://docs.google.com/document/d/13-68OqiU7ISE8U2KPRUXT2ISeBl3WPhXjGD FH52eWlU. (https://docs.google.com/document/d/13-68OqiU7ISE8U2KPRUXT2ISeBl3WPhXjGDFH52eWlU)
- r223908; a213293. PJ2 EA801: repositório de desenvolvimento do projeto. GitHub, 2026. Disponível em:https://github.com/r223908/pj2_ea801_r223908_a213293.
- r223908; a213293. PJ3 EA801: repositório de desenvolvimento do projeto. GitHub, 2026. Disponível em:https://github.com/r223908/pj3_ea801_r223908_a213293.
- Ledbelly2142. VL6180X: Micropython driver for VL6180X on ESP32. GitHub, 2026. Disponível em:https://github.com/Ledbelly2142/VL6180X/blob/master/vl6180x.py.
- STMICROELECTRONICS. VL6180X: Proximity and ambient light sensing (ALS)
module. STMicroelectronics, [S. d.]. Disponível em: VL6180X | Product -
STMicroelectronics (https://www.st.com/en/imaging-and-photonics-solutions/vl6180x.html)

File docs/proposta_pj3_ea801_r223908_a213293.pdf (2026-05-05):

## UNICAMP - Universidade Estadual de Campinas

FEEC - Faculdade de Engenharia Elétrica e de Computação

Câmbio CVT (v2) com BitDogLab V7 PROPOSTA DE PROJETO

Link deste documento (acesso Comentador para UNICAMP): Link (https://docs.google.com/document/d/12xUf4pp4VCcdJPwbZHKw6q6G0AQpYL8BC8JdEnKDbEA/edit?usp=sharing) Repositório no GitHub (https://github.com/r223908/pj3_ea801_r223908_a213293)

Arthur Lucas Da Silva Nogueira | RA: 213293
Raul Galdino Tancredo | RA: 223908

Prof. Eric Rohmer

Campinas
2026

### 1. Descrição do sistema

O sistema desenvolvido consiste na implementação de uma bancada de testes para um Câmbio de Transmissão Continuamente Variável (CVT) simulado, controlado remotamente via interface sem fio. O projeto utiliza a plataforma BitDogLab V7 como unidade central de processamento, integrando comunicação serial, controle de potência e telemetria. O controle é dividido em dois eixos de atuação:

- Eixo motor: Um motor de corrente contínua (DC), simulando a rotação do motor primário, controlado via PWM mas com rotação travada em 100% para regime constante.
- Em casos de partida, parada e mudança de sentido, é feita uma rampa de velocidade.
- Atuador do câmbio: Um segundo motor acoplado a um sistema de fuso (atuador linear), responsável por alterar a posição física da correia do câmbio CVT.
- Agora com controle em malha fechada com sensor de distância, para ter um controle linear da posição do câmbio.

A interface homem-máquina (IHM) é realizada de forma remota através de um módulo Bluetooth (conectado à interface UART da placa) com a integração de um aplicativo no celular. O display OLED da placa é utilizado para exibir a telemetria em tempo real.
A realimentação da posição do atuador do CVT é realizada por meio de um sensor de distância óptico Time of Flight (ToF) VL6180X - A escolha deste sensor se dá por conta do tamanho e interface de comunicação (I2C). Cabe ressaltar que o atual protótipo apresenta diversas otimizações mecânicas e elétricas em relação ao projeto original desenvolvido na etapa anterior da disciplina (PJ2).

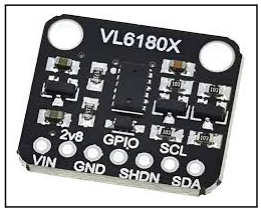
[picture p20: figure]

Figura 1 - Novo sensor de distância ToF VL6180X.

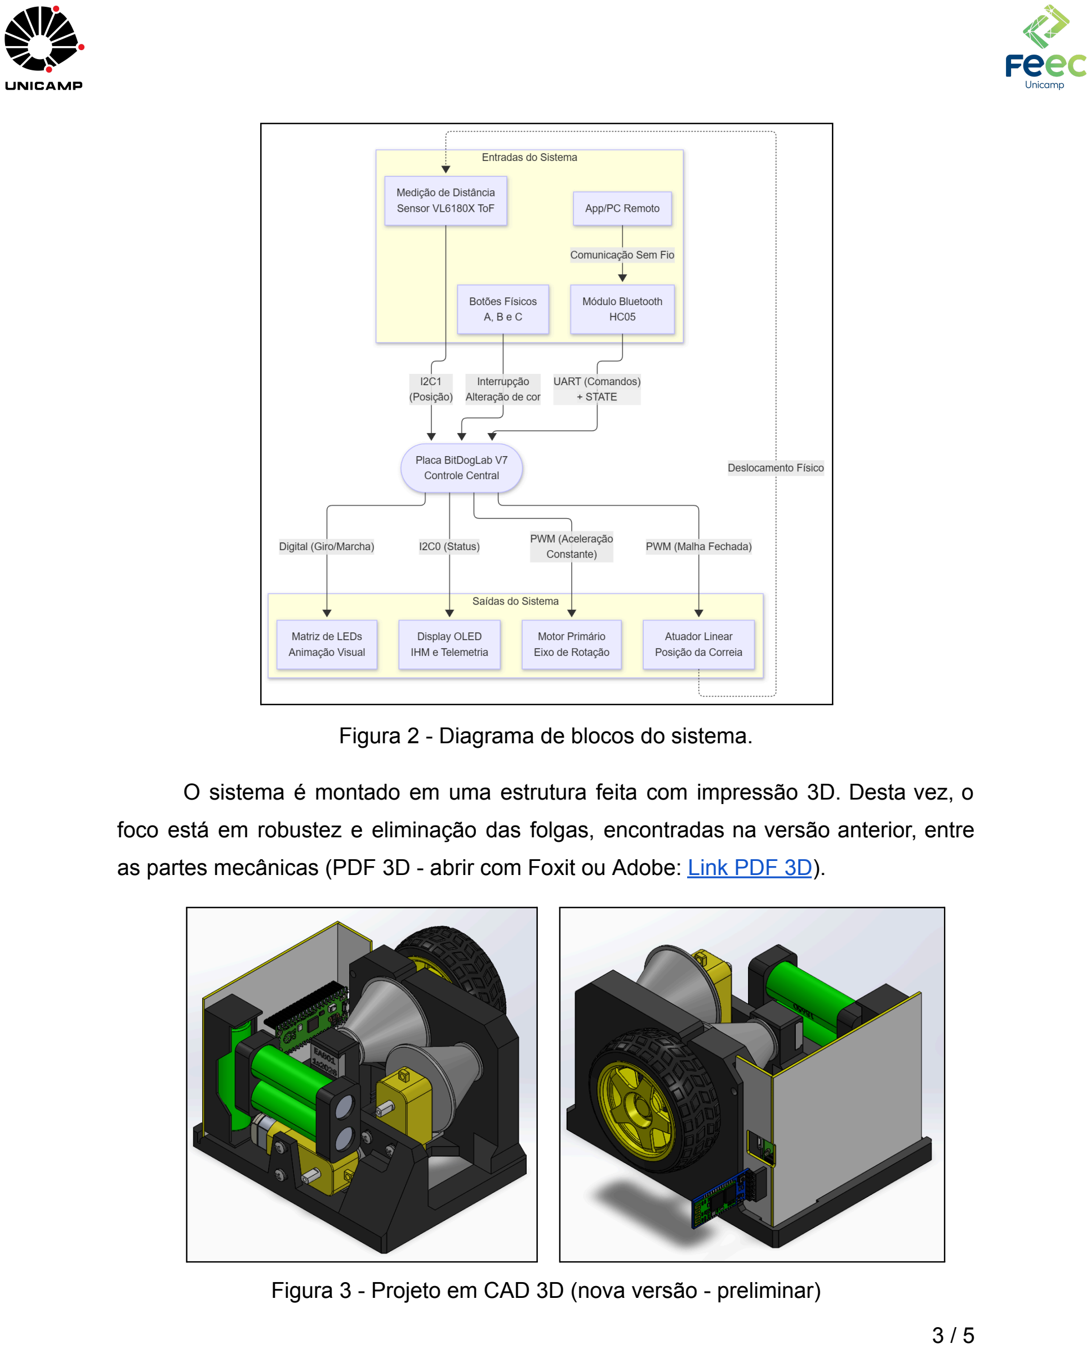
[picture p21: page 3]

Figura 2 - Diagrama de blocos do sistema.

O sistema é montado em uma estrutura feita com impressão 3D. Desta vez, o foco está em robustez e eliminação das folgas, encontradas na versão anterior, entre as partes mecânicas (PDF 3D - abrir com Foxit ou Adobe: Link PDF 3D). (https://github.com/r223908/pj3_ea801_r223908_a213293/blob/main/docs/6_CAD-files/ea801_pj3_cvt_pdf3D.PDF)

Figura 3 - Projeto em CAD 3D (nova versão - preliminar)

### 2. Lista preliminar de peças

- BitDogLab V7.
- Ponte H L293D (CI) para ambos os motores.
- Sensor ToF VL6180X.
- Módulo Bluetooth HC-05
- Placa de fenolite para a shield da BitDogLab
- Jumpers.
- Pilhas 18650 (estima-se 2x para os motores e 1x para a BitDogLab).
- Anel o-ring ou elástico para o câmbio.
- Elementos de fixação:
- 1x Parafuso ISO 4017 M6x15 (Contra-eixo do cone principal)
- 1x Parafuso ISO 4017 M6x60 (fuso do CVT)
- 2x Porca ISO 4032 M6 (Espaçador no fuso do CVT e guia da polia)
- 1x Arruela ISO 7093 Ø6 (Espaçador no fuso do CVT)
- 4x Parafuso auto atarrachante 9/64"x1" (ou 1/8"x1" - Ø x Comprimento)
- Peças impressas em 3D
- Cabo micro USB (apenas para a programação do equipamento).
- Ambiente de desenvolvimento configurado para MicroPython.

### 3. Resultados esperados

Ao final deste projeto, espera-se obter melhores resultados do que os obtidos no PJ2, obtendo um sistema robusto e confiável que demonstre excelência tanto em sua execução física quanto lógica.
- Integração eletromecânica: sistema mecânico estruturalmente confiável e estável - escolha adequada de materiais, fixações, motores e organização segura do circuito eletrônico de potência.
- Arquitetura de Software: No âmbito lógico, almeja-se entregar um software embarcado rigorosamente documentado, modular e eficiente.
- Sistema eletrônico: Espera-se projetar, documentar e implementar uma shield para o conector IDC da BitDogLab de modo que as conexões fiquem seguras e as configurações elétricas possam ser replicadas facilmente.

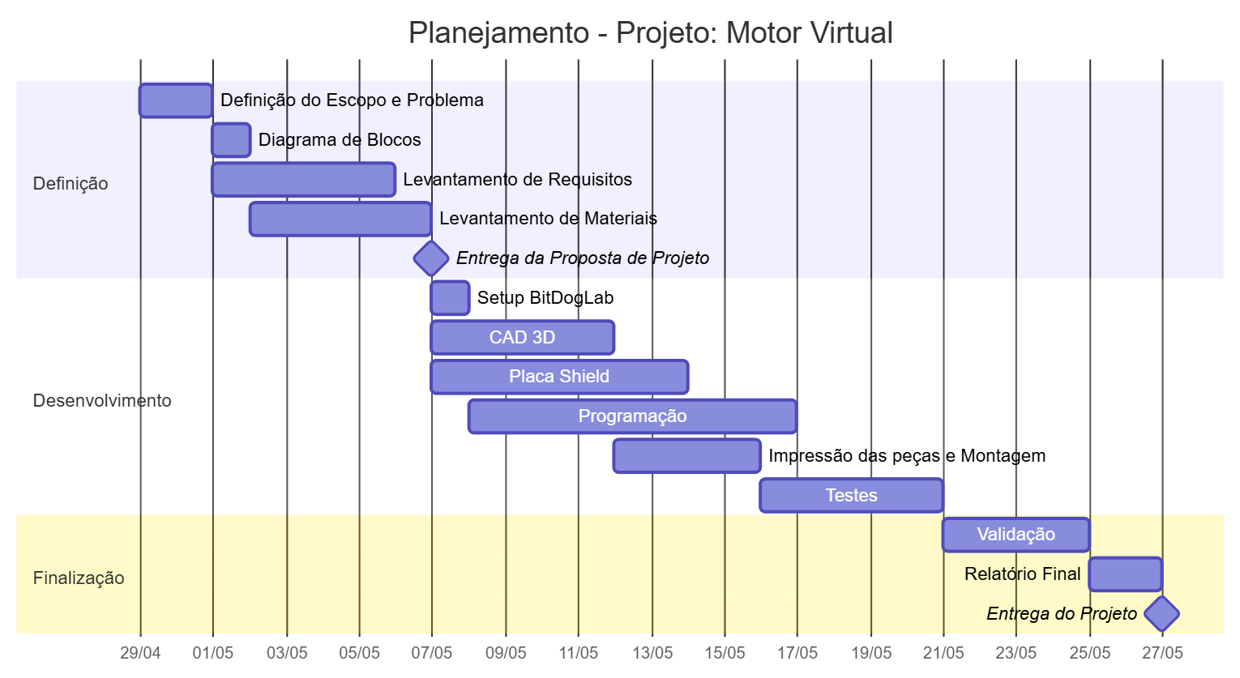
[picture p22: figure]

Figura 4 - Planejamento de projeto.

### 4. Referências

- FRUETT, F. BitDogLab V7: repositório oficial. Campinas: Unicamp, 2024. Disponível em: https://gitlab.unicamp.br/fabiano/bitdoglab-v7.
- FRUETT, F. Banco de informações da BitDogLab V7. [S. l.], 2024. Disponível em: https://docs.google.com/document/d/13-68OqiU7ISE8U2KPRUXT2ISeBl3WPhXjGD FH52eWlU. (https://docs.google.com/document/d/13-68OqiU7ISE8U2KPRUXT2ISeBl3WPhXjGDFH52eWlU)
- r223908; a213293. PJ2 EA801: repositório de desenvolvimento do projeto. GitHub, 2026. Disponível em:https://github.com/r223908/pj2_ea801_r223908_a213293.
- r223908; a213293. PJ3 EA801: repositório de desenvolvimento do projeto. GitHub, 2026. Disponível em:https://github.com/r223908/pj3_ea801_r223908_a213293.
- Ledbelly2142. VL6180X: Micropython driver for VL6180X on ESP32. GitHub, 2026. Disponível em:https://github.com/Ledbelly2142/VL6180X/blob/master/vl6180x.py.
- STMICROELECTRONICS. VL6180X: Proximity and ambient light sensing (ALS)
module. STMicroelectronics, [S. d.]. Disponível em: VL6180X | Product -
STMicroelectronics (https://www.st.com/en/imaging-and-photonics-solutions/vl6180x.html)

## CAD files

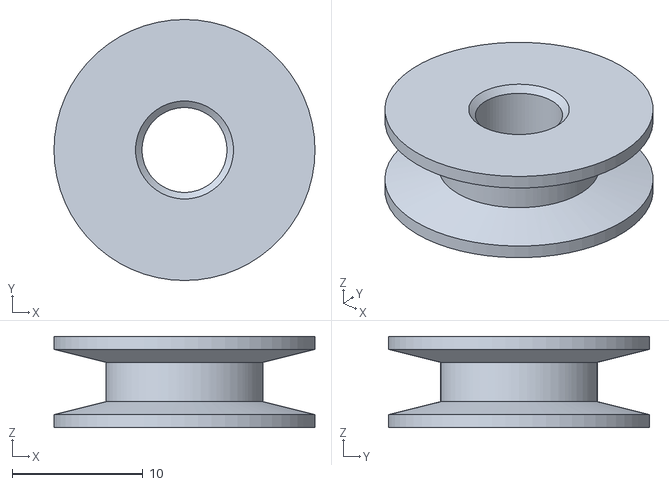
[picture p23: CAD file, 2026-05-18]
docs/6_CAD-files/4_polia_v2.STL
20.0 x 20.0 x 7.00

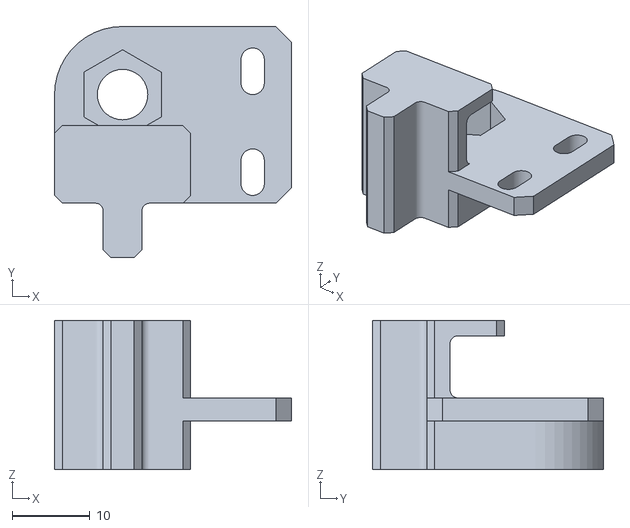
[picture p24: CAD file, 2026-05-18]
docs/6_CAD-files/5_guia_polia_v2.STL
30.5 x 29.8 x 19.2

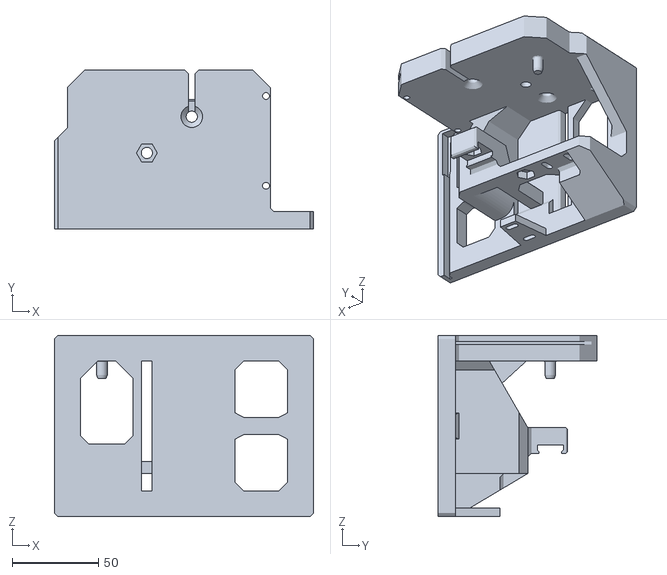
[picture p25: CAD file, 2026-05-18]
docs/6_CAD-files/1_base_v2.STL
150.0 x 92.0 x 105.0

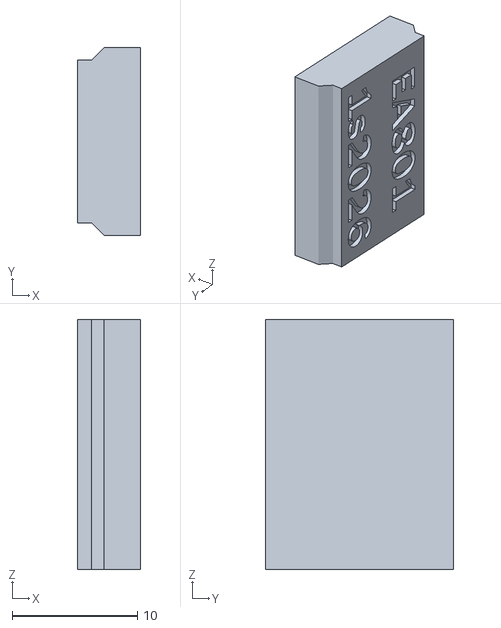
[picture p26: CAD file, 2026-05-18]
docs/6_CAD-files/6_cunha.STL
5.00 x 15.0 x 20.0

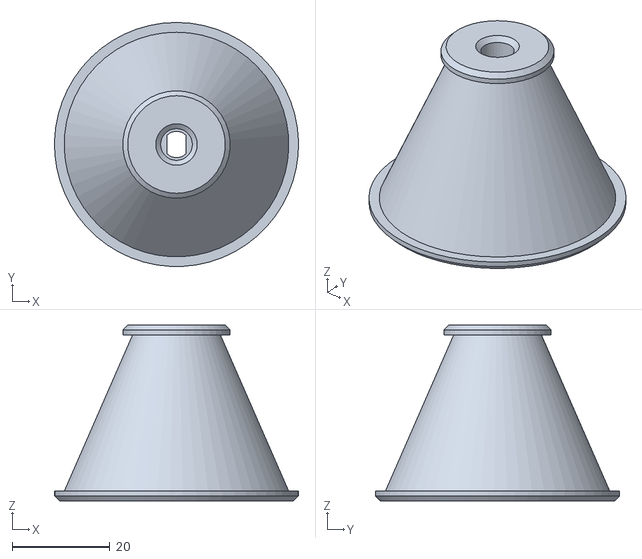
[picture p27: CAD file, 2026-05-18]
docs/6_CAD-files/2_cone_motor_v2.STL
50.0 x 50.0 x 36.0

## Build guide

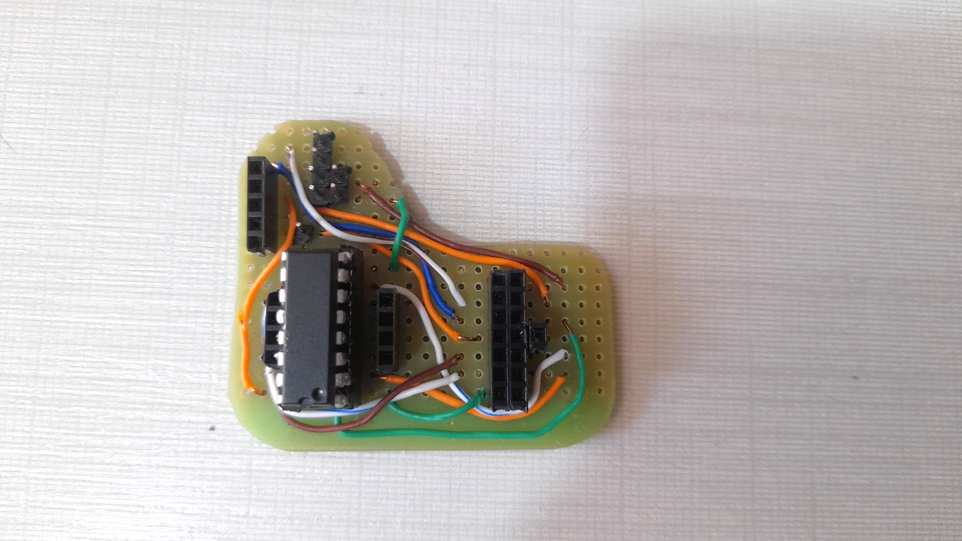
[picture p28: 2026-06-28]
docs/2_images/1_montagem/placa_2.jpg

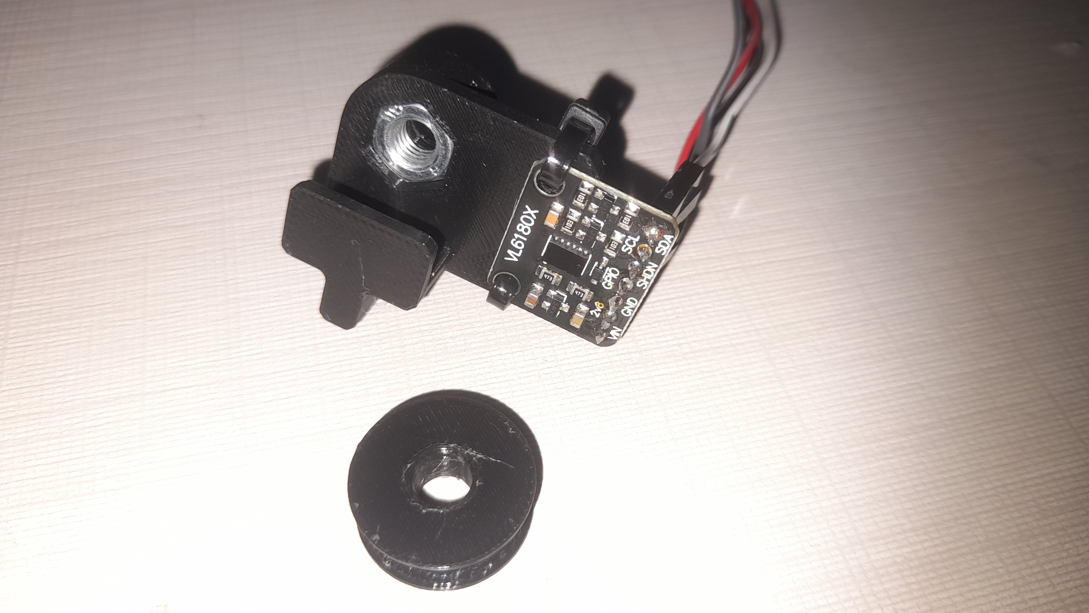
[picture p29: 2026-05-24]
docs/2_images/1_montagem/cambio_3.jpg

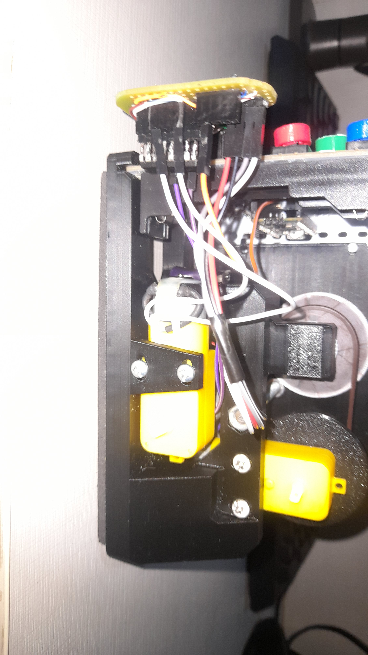
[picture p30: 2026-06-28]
docs/2_images/1_montagem/geral_8.jpg

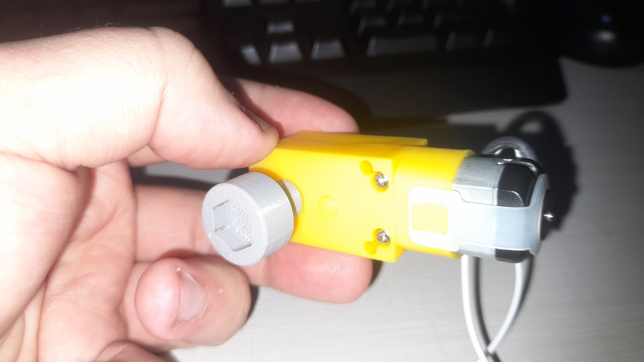
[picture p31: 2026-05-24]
docs/2_images/1_montagem/cambio_5.jpg

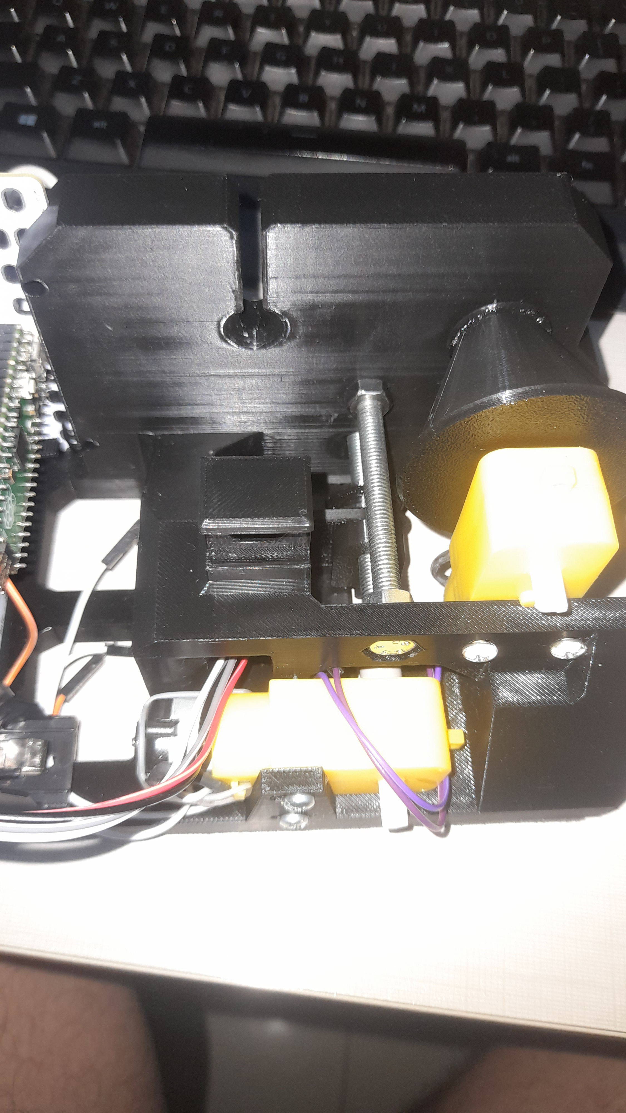
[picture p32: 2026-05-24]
docs/2_images/1_montagem/geral_3.jpg

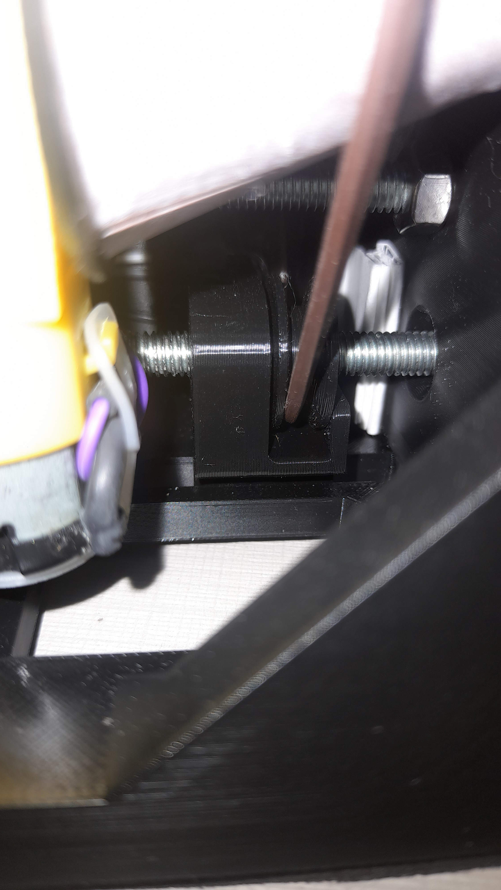
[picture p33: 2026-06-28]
docs/2_images/1_montagem/tof_6.jpg

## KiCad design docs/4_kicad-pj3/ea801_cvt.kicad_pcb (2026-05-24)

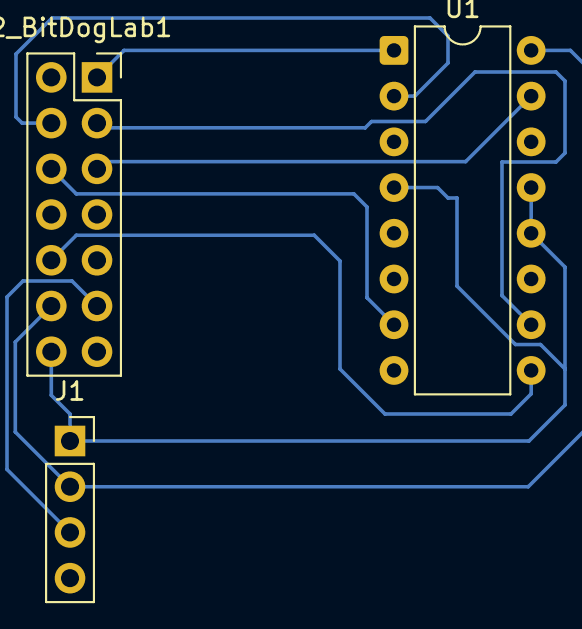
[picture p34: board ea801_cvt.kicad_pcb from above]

Board: 2 copper layers, 3 parts (0 on the bottom side), 10 nets.

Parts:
J1: Conn_01x04; PinSocket_1x04_P2.54mm_Vertical
J2_BitDogLab1: J2_IDC_BitDogLab; PinSocket_2x07_P2.54mm_Vertical
U1: L293D; DIP-16_W7.62mm

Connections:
/3V3: J1.2, J2_BitDogLab1.3V3 (Pin_2), U1.16 (VCC1)
/GP8: J1.SDA, J2_BitDogLab1.GP8 (Pin_13)
/GP9: J1.SCL, J2_BitDogLab1.GP9 (Pin_12)
/GP16: J2_BitDogLab1.GP16 (Pin_6), U1.2 (1A)
/GP17: J2_BitDogLab1.GP17 (Pin_5), U1.7 (2A)
/GP19: J2_BitDogLab1.GP19 (Pin_9), U1.10 (3A)
/GP20: J2_BitDogLab1.GP20 (Pin_10), U1.15 (4A)
/GP28: J2_BitDogLab1.GP28 (Pin_3), U1.9 (EN3,4)
GND: J1.1, J2_BitDogLab1.GND (Pin_1), U1.4 (GND), U1.5 (GND), U1.12 (GND), U1.13 (GND)
unnamed: J2_BitDogLab1.GP18 (Pin_8), U1.1 (EN1,2)

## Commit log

2026-05-01 upload do projeto novo do kicad
    [ea801_cvt.kicad_pcb, ea801_cvt.kicad_sch]
2026-05-04 datasheet do ToF e testes
    [ea801_cvt.kicad_pcb, ea801_cvt.kicad_sch]
2026-05-05 att readme, inclusão imagens e diagrama de blocos do sistema
2026-05-05 att imagem do diagrama de blocos e teste com escalas das imagens no readme; att readme no link do pdf 3D
2026-05-05 renomeando a pasta 1_datasheets para 1_folha-de-dados, att readme e inc imagem do gantt do pj3
2026-05-18 upload arquivos .stl
    [1_base_v2.STL, 2_cone_motor_v2.STL, 3_cone_saida_v2.STL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]
2026-05-23 revisao de alguns pontos e inicio dos testes com 3D
    [3_cone_saida_v2.STL]
2026-05-24 inc imagens, att projeto kicad e att dos arquivos do sensor ToF
    [ea801_cvt.kicad_pcb, ea801_cvt.kicad_sch]
2026-06-08 upload of functioning l293d config and ToF reading; toDO: ToF control of CVT motor
2026-06-14 commit da versão que funcionou tudo
2026-06-27 asbuilt do projeto do schematic
    [ea801_cvt.kicad_sch]
2026-06-27 trash files from kicad
